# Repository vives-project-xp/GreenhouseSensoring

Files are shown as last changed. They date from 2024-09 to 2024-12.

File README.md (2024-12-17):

# GreenhouseSensoring

## Inhoudsopgave

- [GreenhouseSensoring](#greenhousesensoring)
  - [Inhoudsopgave](#inhoudsopgave)
  - [Doel](#doel)
  - [Gebruik](#gebruik)
  - [Team](#team)
  - [Sensoren](#sensoren)
- [Meer informatie nodig?](#meer-informatie-nodig)
  - [Alle sensoren uitgelegd:](#alle-sensoren-uitgelegd)
  - [Handleiding voor gebruikers:](#handleiding-voor-gebruikers)
  - [Technische documentatie:](#technische-documentatie)
  - [Tips voor mogelijke uitbreidingen en verbeteringen](#tips-voor-mogelijke-uitbreidingen-en-verbeteringen)
- [Bill of Materials (BOM)](#bill-of-materials-bom)

## Doel
Dit project heeft als einddoel het maken van testopstelling voor het meten van verschillende eigenschappen in de serre m.b.v. sensoren en deze waarden uit te lezen met Home Assistant. Aan de hand van 6 sensoren, die in totaal 9 verschillende parameters doorsturen, worden metingen opgenomen via een ESP32 microcontroller. Deze ESP32 stuurt dan via het lokale netwerk de gemeten waardes door naar de lokale Home Assistant server, waar ze op een visuele manier mooi voorgesteld kunnen worden. Op die manier kan informatie opgedaan worden om de planten zo goed mogelijk te verzorgen. Want meten is weten! 

Daarnaast werd ook [technische documentatie](./Documentatie/Technische_documentatie.md) en een [lijst van mogelijke uitbreidingen/verbeteringen](./Documentatie/Mogelijke_uitbreiding.md) opgesteld zodat hierop verder gebouwd kan worden. Ook is er een [handleiding](./Documentatie/Handleiding_gebruiker.md) ter beschikking voor mensen die het product willen gebruiken.

## Gebruik
Het gebruiken van het product is vrij simpel. Wanneer deze in het stopcontact gestopt is, zou de ESP na enkele seconden automatisch verbinding moeten maken. Als deze verbinding kan maken met het Devbit netwerk, zullen de waarden doorgestuurd worden naar home assistant. Indien geen verbinding gemaakt kan worden, zal ook niets verstuurd kunnen worden (ook eventuele seriële data zal niet verstuurd worden). Voor enkele sensoren kan het enkele seconden tot een minuutje duren voor ze hun waardes doorsturen.

## Team
De groep bestaat uit:  
- [Didier Vereecke](https://github.com/MrI2C) • Projectleader
- [Xander Vyvey](https://github.com/vyx04) • Scrum-master
- [Ruben Belligh](https://github.com/RubenBelligh)    
- [Kenrie Vandekerckhove](https://github.com/Kenrie19)  

## Sensoren
Dit zijn de sensoren die we gaan gebruiken:
- **Temperatuur/Vochtigheid Sensor**: Meet zowel de temperatuur als de luchtvochtigheid binnen de serre.
- **Lichtintensiteitssensor**: Meet de hoeveelheid licht die de planten ontvangen.
- **Bodemvochtsensor**: Meet het vochtgehalte van de grond.
- **Bodemtemperatuursensor**: Meet de temperatuur van de grond.
- **CO2-sensor**: Meet het CO2-gehalte in de lucht binnen de serre.
- **NPK Sensor**: Meet de concentraties van stikstof (N), fosfor (P), en kalium (K) in de bodem.

# Meer informatie nodig?
## Alle sensoren uitgelegd:
  - [Algemene informatie sensoren](./Documentatie/Algemene%20info%20componenten/README.md)

## Handleiding voor gebruikers:
  - [Handleiding](./Documentatie/handleiding.md)

## Technische documentatie:
- [Technische documentatie](./Documentatie/Technische_documentatie.md)

## Tips voor mogelijke uitbreidingen en verbeteringen:
  - [Uitbreidingen](./Documentatie/Mogelijke_uitbreiding.md)

# Bill of Materials (BOM)

| **Aantal** | **Korte Omschrijving** | **Totale Kostprijs (excl. BTW)** |
|---|---|---|
| 1 | ESP | € 9,50 |
| 1 | Adapter voor ESP | € 3,22 |
| 1 | Temperatuurs/vochtigheid sensor | € 3,30 |
| 1 | Lichtintensiteitssensor | € 2,23 |
| 1 | CO2 Sensor | € 35,95 |
| 1 | Bodemvochtsensor | € 2,48 |
| 1 | Voedingstofsensor | € 45,35 |
| 3 | Bodemtemperatuur sensor | € 14,83 |
| 1 | TTL to RS485 converter | € 1,57 |
| 3 | Level shifter | € 1,61 |
| 6 | USB-connector met schroefaansluiting | € 4,95 |
| 1 | Verlengkabel USB | € 5,78 |
| 1 | Stekkerkop | € 5,36 |
| 10 | Draden van 0,5mm² (oranje) | € 1,60 |
| 10 | Draden van 0,5mm² (zwart) | € 4,00 |
| 10 | Draden van 0,5mm² (rood) | € 1,40 |
| 10 | Draden van 0,5mm² (wit) | € 1,60 |
| 1 | Adereindhulzen voor 0,5mm² | € 2,31 |
| 6 | Wago's 5P | € 4,93 |
| |Totaal | € 151,97 |

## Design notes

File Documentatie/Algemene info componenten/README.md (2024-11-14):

# Architectuur:
De **ESP32 Devkit V1** board wordt gebruikt als microcontroller voor de aansturing. De ESP zal in een 3D-geprinte behuizing geplaatst worden en verbonden worden aan een speciale adapter om kabels eenvoudiger te kunnen bevestigen.

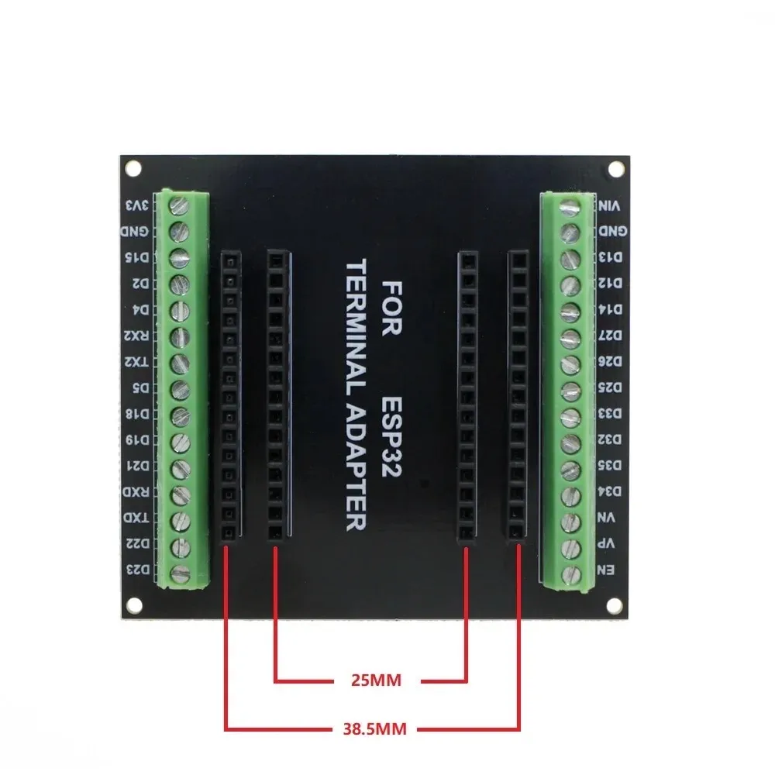
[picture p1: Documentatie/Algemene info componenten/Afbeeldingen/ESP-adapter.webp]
ESP Adapter


# ESP32
De minimale stroomvoorziening voor de ESP32 is 500 mA.

# Sensoren
De volgende 6 sensoren worden gebruikt voor het monitoren van de planten:

## Temperatuur- en vochtsensor omgeving
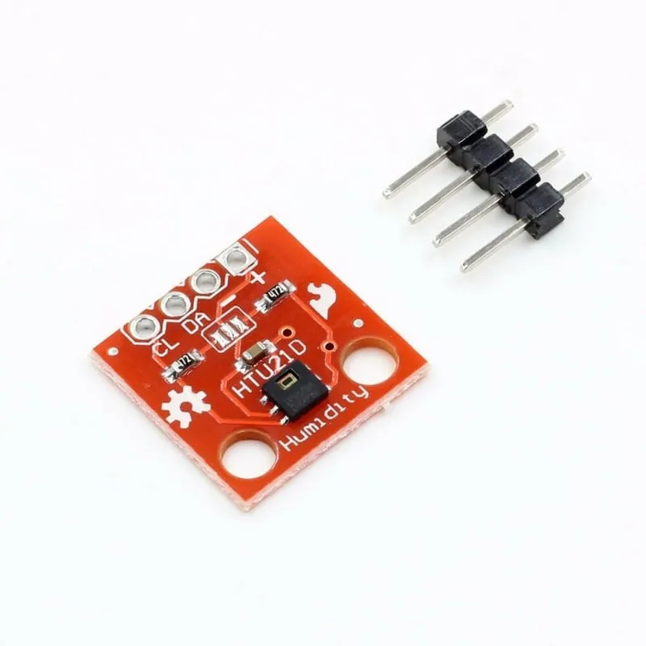
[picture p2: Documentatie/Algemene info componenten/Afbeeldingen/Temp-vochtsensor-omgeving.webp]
Temperatuur- en vochtsensor omgeving


- **Beschrijving:** Deze sensor (Temperatuur/Vochtigheid Sensor Module Breakout - HTU21D (OT3567)) meet zowel de temperatuur als de luchtvochtigheid in de omgeving van de serre. Hiervoor zal een klein doosje geprint worden om deze veilig op te bergen.
- **Elektrische eigenschappen:** Gevoed op 3.3V, direct via de ESP. Stroomverbruik ligt tussen 300 en 500 µA in actieve toestand (tussen 0.02 en 0.14 µA in slaapstand).
- **Overig:** Heeft SCL/SDA-pinnen die rechtstreeks op pin D21 en D22 van de ESP aangesloten kunnen worden. Een andere sensor (lichtsensor) gebruikt ook SCL/SDA, maar beide sensoren hebben een ander I2C-adres, wat geen probleem oplevert. Deze sensor werkt op adres **0x40**.
- **Bronnen:**
  - [Verkooppagina Otronic](https://www.otronic.nl/nl/temperatuur-vochtigheid-sensor-module-breakout-htu.html)

## Lichtintensiteitsensor
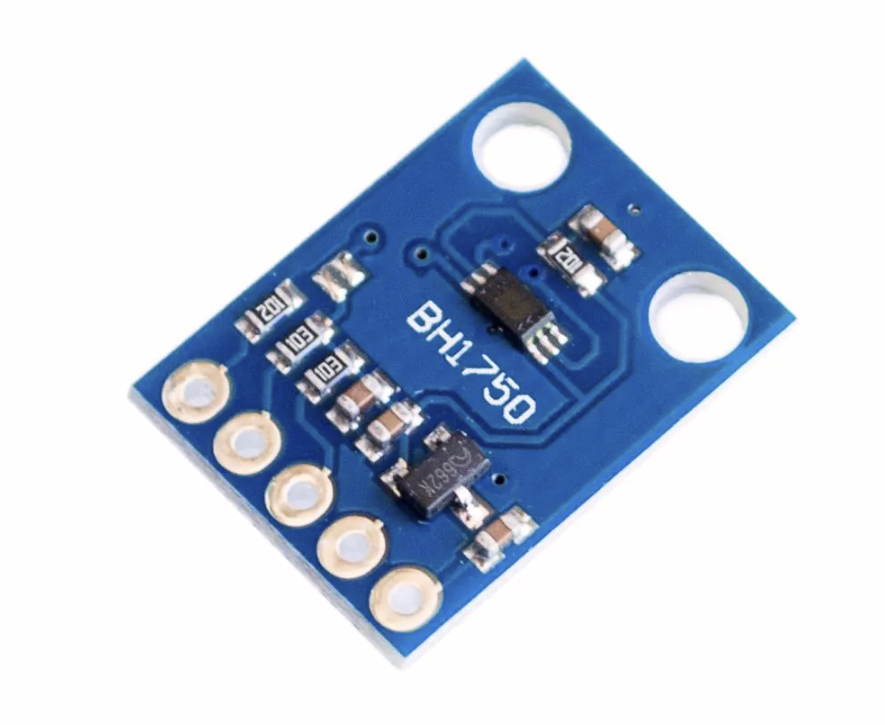
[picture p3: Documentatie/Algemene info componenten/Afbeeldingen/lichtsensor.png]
Lichtintensiteitssensor


- **Beschrijving:** Deze sensor meet de lichtsterkte in de serre en zal op enige afstand van de ESP bevestigd worden in een 3D-geprint doosje. Deze sensor werkt via I2C en heeft twee mogelijke adressen: **0x5C** (als ADDR hoog is) of **0x23** (als ADDR laag is).
- **Elektrische eigenschappen:** Werkt bij een spanning tussen 3V en 5V.
- **Bronnen:**
   - [Verkooppagina Otronic](https://www.otronic.nl/nl/lichtintensiteitssensor-bh1750-16-bit-i2c.html)
  - [Voorbeeldcode met Arduino](https://randomnerdtutorials.com/guide-for-ds18b20-temperature-sensor-with-arduino/)
  - [Instructables Tutorial](https://www.instructables.com/How-to-use-DS18B20-Temperature-Sensor-Arduino-Tuto/)

## Co² sensor
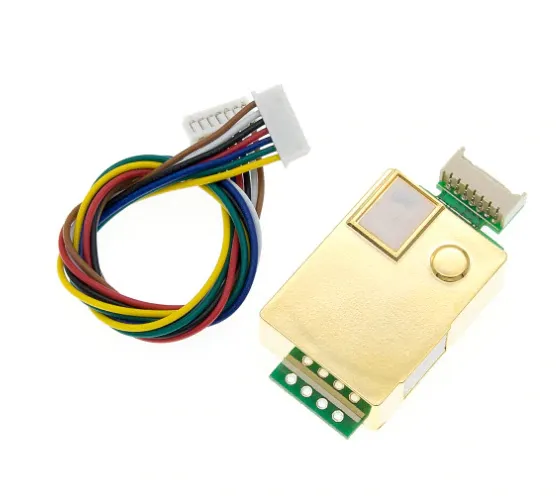
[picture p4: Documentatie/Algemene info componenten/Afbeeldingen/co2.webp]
Co² sensor


- **Beschrijving:** Deze sensor meet de kwaliteit van de lucht (Co² en stikstof). Dit zal in een doosje in een doosje zitten met gaten zodat deze nog goed kan meten. Signalen worden verstuurd door TX en RX uitgang. 
- **Elektrische eigenschappen:** Werkt bij een voeding van 4.5-5.5V DC.
- **Bronnen:**
  - [Verkooppagina Otronic](https://www.otronic.nl/nl/co2-sensor-mh-z19b-met-kabeltje.html)

## Bodemvochtsensor
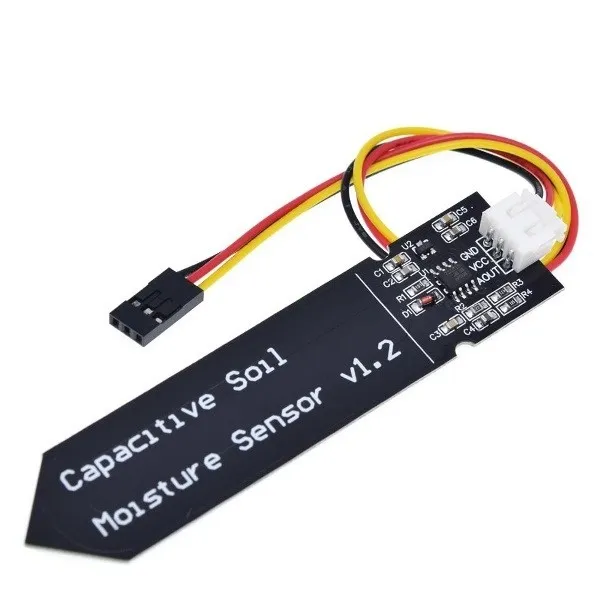
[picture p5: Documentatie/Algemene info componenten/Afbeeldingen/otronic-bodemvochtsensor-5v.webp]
bodemvochtsensos

- **Beschrijving:** Deze sensor zal de vochtigheid meten van onze grond. Deze wordt gevoed met 5V voeding. Met een signaalkabel worden de gegevens naar de esp gezonden.
- **Elektrische eigenschappen:** Deze sensor werkt op 5V.
- **Bronnen:**
  - [Verkooppagina Otronic](https://www.otronic.nl/nl/bodemvochtsensor-met-voltage-regulator-copy.html)

## Bodemtemperatuursensor
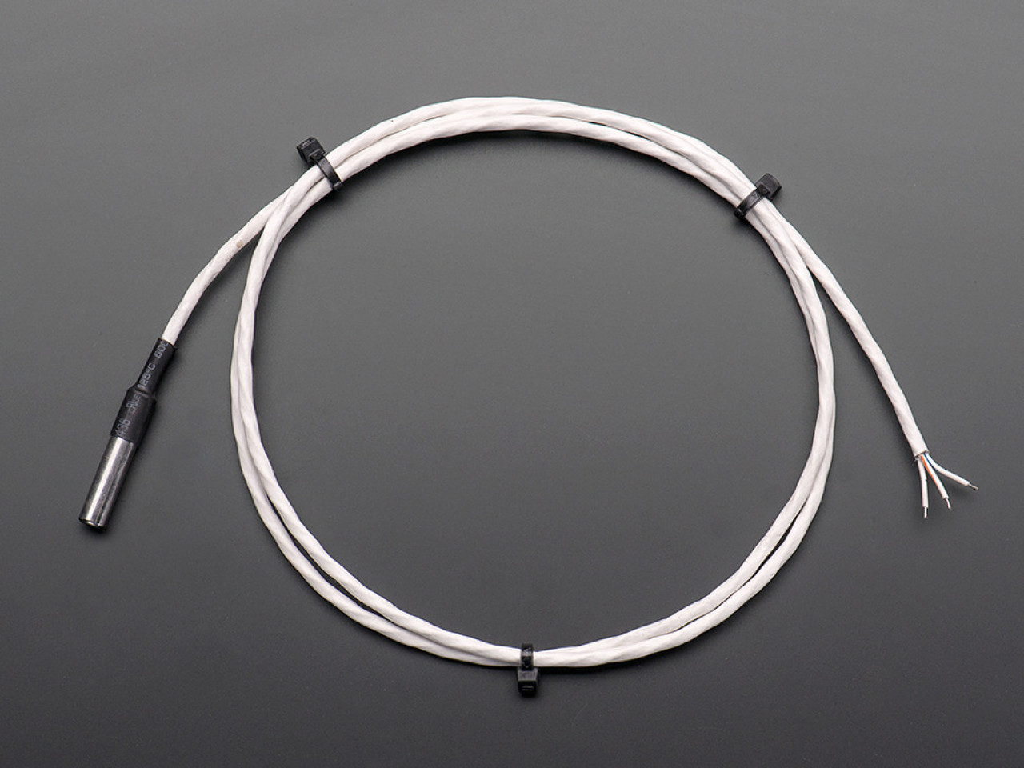
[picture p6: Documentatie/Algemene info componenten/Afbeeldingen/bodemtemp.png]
Bodemtemperatuursensor

- **Beschrijving:** Dit is een Bodemtemparatuursensor en zal in de grond zitten. Waar het de temperatuur zal meten, dit wordt doorgestuurd met een signaal kabel naar de esp.
- **Elektrische eigenschappen:** Werkbaar bij een spanning tussen 3.0V en 5.5V.
- **Overige:** Werkt tussen de -55 en 125 graden.
- **Bronnen:**
  - [Verkooppagina Kiwi Electronics](https://www.kiwi-electronics.com/nl/hoge-temp--waterbestendige-ds18b20-digitale-temperatuursensor-plus-weerstand-1431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)

## Voedingstofsensor
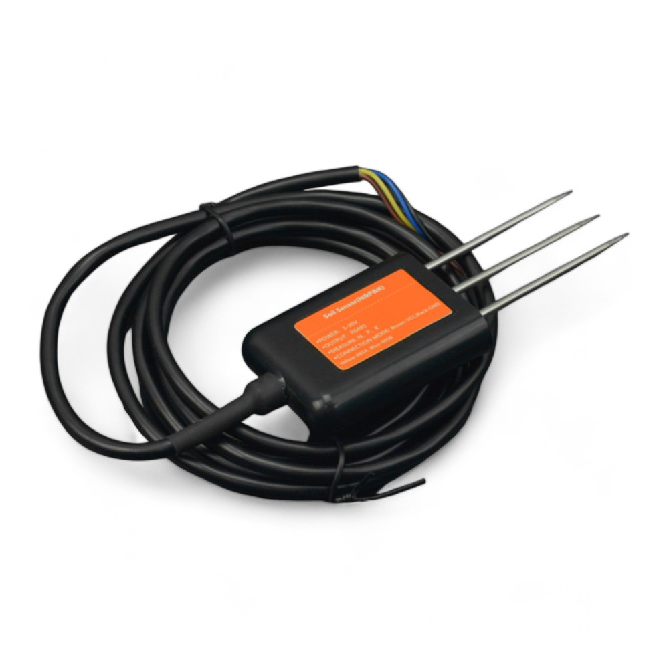
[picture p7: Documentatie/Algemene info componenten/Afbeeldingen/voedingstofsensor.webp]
Voedingstofsensor

- **Beschrijving:** De voedingstofsensor ookwel NPK sensor genoemd meet drie dingen uit. De stikstof, de fosfor en de kalium. Dit kan niet rechtstreeks uitgemeten worden op de esp, hiertussen moet je een TTL -> RS485 plaatsen. Om een goed signaal te kunnen krijgen op de esp.
- **Elektrische eigenschappen:** Deze sensor werkt tussen de  5V en 30V.
- **Overige:** Maximum temperatuur is 80°C.
- **Bronnen:** 
  - [Verkooppagina Mouser](https://www.mouser.be/ProductDetail/DFRobot/SEN0605?qs=sGAEpiMZZMu3sxpa5v1qrmro%252BbykgF%2FHBGnWfOZZDls%3D)
  - [Aansluitschema's](https://how2electronics.com/iot-based-soil-nutrient-monitoring-with-arduino-esp32/#:~:text=So,%20this%20is%20how%20you%20can%20make%20a)

# Schema van de aansluitingen
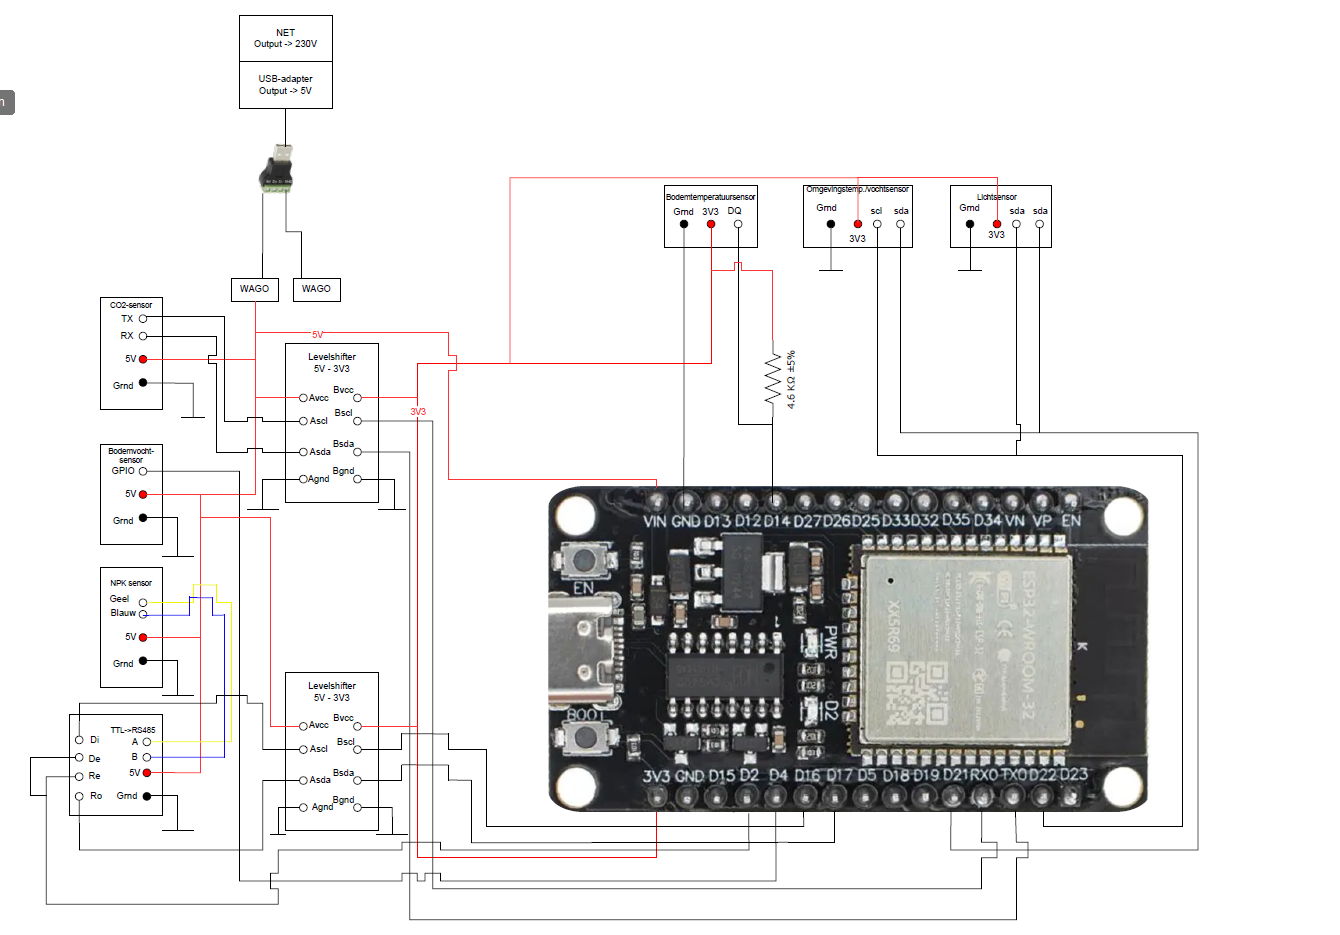
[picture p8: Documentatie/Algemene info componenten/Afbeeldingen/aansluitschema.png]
aansluitschema


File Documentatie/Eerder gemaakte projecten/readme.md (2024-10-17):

1. Info over de vochtigheidsSensor en NPK sensor

https://how2electronics.com/iot-based-soil-nutrient-monitoring-with-arduino-esp32/#:~:text=So,%20this%20is%20how%20you%20can%20make%20a

2. UV sensor aansluiting

https://youtu.be/UsLcHSbxf_8

3. Aansluiting voor de CO2 sensor

https://www.electroniclinic.com/mh-z19b-ndir-co2-sensor-with-arduino-mhz19b/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

4. Bodemvochtsensor / temperatuur

https://microcontrollerslab.com/esp32-htu21d-temperature-humidity-sensor-tutorial/

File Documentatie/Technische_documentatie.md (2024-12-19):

# Technische documentatie

In dit document werd alle benodigde technische documentatie van de testopstelling samengebracht om eventueel te kunnen bouwen hierop. Specifieke schema's of datasheets zijn te vinden onder de mapjes [Hardware](../Hardware/) en [Datasheets](../Datasheets/). Mogelijke uitbreidingen of verbeteringen voor het product zijn in [dit bestand](./Mogelijke_uitbreiding.md) te vinden. Ook is er een [handleiding](./Handleiding_gebruiker.md) voor het gebruik van het product als eindgebruiker. Het wordt aangeraden om al deze documenten eerst door te nemen alvorens dit document te gebruiken.

## Inhoudsopgave

- [Technische documentatie](#Technische-documentatie)
  - [Extra sensoren toevoegen aan project](#Extra-sensoren-toevoegen-aan-project)
  - [Vervangen tijdelijke ESP32](#Vervangen-tijdelijke-ESP32)
  - [Toevoegen omgevingstemperatuursensor](#Toevoegen-omgevingstemperatuursensor)
  - [Overige info ESP32](#Overige-info-ESP32)

## Extra sensoren toevoegen aan project
In dit onderdeel wordt besproken hoe je nieuwe sensoren kan toevoegen aan dit project.

### Stap 1
Denk na over wat je wilt meten en welke sensor je hiervoor kan gebruiken. Deze sensor kan alleen op 5V of 3.3V werken. Indien een sensor op een hogere spanning werkt, zal dit niet compatibel zijn met ons systeem en zal een aparte manier van voeden gebruikt moeten worden voor die component. Ook is het gebruik van een step-down-converter aangeraden om de ESP32 niet te beschadigen.

### Stap 2
Maak met de datasheets een architectuurschema zodat je zeker weet hoe deze sensor aan te sluiten is op de ESP. Later kun je o.a. bij fouten hierop terugkomen, een duidelijk schema is dus van groot belang! Kijk hierbij ook van welk communicatieprotocol de sensor gebruik maakt en welke pinconfiguraties hier voor nodig zijn.

### Stap 3
Schrijf de code voor de ESP zodat deze de sensorwaardes kan weergeven (serieel om te testen en/of via home assistant) In veel gevallen is voorbeeldcode online te vinden als je het specifieke typenummer van de sensor opzoekt. Deze voorbeeldcode kan vaak een goed vertrekpunt zijn. Je kan ook altijd kijken naar de code van de reeds geïmplementeerde sensoren, hieronder de belangrijkste code van de lichtsensor ter illustratie (zie commentaar ernaast):
```
#include <BH1750.h> // voor deze sensor wordt gebruik gemaakt van deze library. Dit is te dowloaden adhv de platformIO extensie in VS code (ga naar boards en selecteer daar eerst het type bord, daarna kan onder libraries een library gezocht en toegekend aan een project worden)

HaSensor lichtWaarde; // initialisatie van naam sensorwaarde voor home assistant

BH1750 lightMeter;

void setup()
{
  lightMeter.begin(); // initialiseren van lightmeter in setup

  if (!lightMeter.begin()) { //optionele error-handling
    Serial.println("BH1750 initialisatie mislukt! Controleer de verbinding.");
  }

  //connectie met home assistant opzetten:
  connection =  HaConnection(WIFI_SSID, WIFI_PASSWORD, "IP-ADRES", 8123);
  connection.setup();
  if (!connection.connected)
    return;

  lichtWaarde = HaSensor("Light", SensorType::LIGHT,0,10000);

}

void loop() { 
  //adhv library data verkrijgen en schrijven:
  float lux = lightMeter.readLightLevel();
  Serial.print("Light: ");
  Serial.print(lux);
  Serial.println(" lx");
  Serial.println("");

  //en versturen naar home assistant:
  lichtWaarde.setValue(lux);
  std::vector<HaSensor> sensors = {lichtWaarde}; // hier kunnen andere sensoren in worden toegevoegd
  connection.sendData("Sensoring", sensors);
  delay(5000);

```

### Stap 4
Als de sensor geleverd is test je deze best eerst even uit in een testopstelling om te kijken of alles werkt. Dit kan bvb. op een breadboard zijn en enkel serieel versturen van data. Dan kan via een applicatie als putty gekeken worden of er waardes gestuurd worden.

### Stap 5
Nu kan je de sensor solderen in de echte opstelling. Doe dit in een veilige omgeving. Als de sensor geplaatst is en werkt dan ben je in principe klaar. Nu kan via home assistant gekeken worden of de waardes correct verstuurd worden (opgelet: op home assistant moeten ook nog enkele dingen opgezet worden, kijk daarvoor in de documentatie van team GH-Networking and monitoring).

## Vervangen tijdelijke ESP32

Om de tijdelijke Devkit V1 te vervangen met de voorziene ESP32 USB-C WROOM, moeten de volgende simpele stappen voldaan worden:

### Stap 1
Eerst en vooral moet de code upgeload worden naar de nieuwe ESP.

### Stap 2
Verwijder de tijdelijke ESP en alle kabels die deze verbinden met het adapterbord. Deze zijn niet meer nodig, waardoor het doosje een stuk overzichterlijker zal worden.

### Stap 3
Hierna moeten de pinaansluitingen voor voor enkele sensoren fysiek veranderd worden. Voor de sensoren die gebruik maken van I2C moet SCL aan pin D22 en SDA aan pin D21 hangen. Aangezien I2C met adressen werkt kunnen beide sensoren aan deze datapinnen hangen. Dit moet dus op het adapterbordje veranderd worden.

### Stap 4
Wanneer de ESP32 nu op de juiste manier op het adapterbordje bevestigd zal worden (kijk hiervoor naar pinnamen op adapter en ESP en kijk of ze overeenkomen), zal alles werken met de nieuwe ESP!

## Toevoegen omgevingstemperatuursensor
Omdat wij door een defect de omgevingstemperatuursensor niet konden gebruiken, zit deze niet inbegrepen in het project op dit moment. Op volgende manier moet deze toegevoegd worden:

### Stap 1
Sluit de sensor aan, raadpleeg hiervoor het [elektrisch schema](../Hardware/Elektrisch_schema_sensoring.pdf) (kijk naar omgevingstemp./vocht rechtsboven in het schema). 

### Stap 2
Verander nu de code zodat de waardes uitgelezen kunnen worden. Hiervoor moet de code die ongeveer staat op lijn 104-105, 166-174 en 188-189 uit comment gezet worden. Upload nu de code naar de ESP en de data zou serieel verstuurd moeten worden. Om deze ook te zien in het dashboard van home assistant moet opnieuw nog het een en ander toegevoegd worden op de home assistant.

## Overige info ESP32
Indien je code wil uploaden naar de tijdelijke (Devkit v1) ESP, moet tijdens het uploaden de boot knop ingedrukt worden, anders verschijnt een error. Let ook bij het uploaden dat andere seriële programma's die de COM-poort gebruiken, zoals Putty, niet meer openstaan.

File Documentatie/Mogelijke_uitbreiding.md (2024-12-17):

# Mogelijke Uitbreidingen
Onze opdracht is het uitwerken van een testopstelling van de sensormogelijkheden voor een serre. Omdat wij uiteraard gaandeweg in ons project aspecten tegenkwamen die beter zouden kunnen of als extraatje toegevoegd kunnen worden, maakten we hieronder een overzicht op van uitbreidingen die mogelijk toegepast kunnen worden bij een definitievere uitwerking van deze testopstelling. 

## Inhoudsopgave
- [Mogelijke Uitbreidingen](#mogelijke-uitbreidingen)
  - [Inhoudsopgave](#inhoudsopgave)
  - [Meer ESP's](#meer-esps)
  - [Nieuwe Sensoren](#nieuwe-sensoren)
  - [Verbeterde Aansluitingen](#verbeterde-aansluitingen)
  - [Geautomatiseerde Rapportage](#geautomatiseerde-rapportage)
  - [Veiligheidsverbeteringen](#veiligheidsverbeteringen)

## Meer ESP's
Omdat wij de functionaliteit willen aantonen van dit concept, en bijkomend ook met een beperkt budget werken, maakten wij gebruik van 1 ESP-microcontroller. We raden bij een uitbreiding van dit project aan om per plantje een aparte esp te gebruiken, zodat je geen problemen opduiken. Er zijn bijvoorbeeld een beperkt aantal UART poorten op de ESP, waarvan 1 al gebruikt wordt om serieel via USB eventueel data te versturen naar een PC bij het testen. Het gebruik van meerdere ESP's zorgt ook voor een overzichtelijkere opstelling en meer variatie in de plaats van de opstelling. Ook wordt door ons aangeraden om een aparte ESP te voorzien voor sensoren die de volledige omgeving meten (omgevingstemperatuur, vocht, CO2, lichtintensiteit).

## Nieuwe Sensoren
- Sapflow sensor
  - Meet de snelheid van het sap op de plant
- pH-sensor
  - Meet de zuurgraad van de bodem
- Chlorofylsensor
  - Meet het chlorofylgehalte in de bladeren.
- UV-sensor
  - Meet hoeveel UV-straling er is (niet hetzelfde al onze sensor die de lichtintensiteit meet uitgedrukt in lux)

## Verbeterde Aansluitingen en ontwerp
Het kan handig zijn om de draadjes met krimpkousen aan te sluiten, nu hebben we dit met plakband gedaan omdat er geen krimpkous of dergelijk materiaal ter beschikking. Ook zou het goed zijn om voor de lichtintensiteitsensor een doosje te printen in doorzichtige print, wat voor ons niet mogelijk was. Wij gebruikten hiervoor een bestaand doorzichtig doosje, maar dit is uiteraard niet specifiek afgestemd op dit product. Daarbij moet dit ook in een speciaal printmateriaal geprint worden dat tegen zonlicht kan.
Tot slot zou het kunnen helpen om het 3D doosje groter maken in breedte en in hoogte en vakjes te maken om de wago's netjes in te plaatsen. Wij maakten ook geen gebruik van een specifiek ontworpen PCB, grotendeels omwille van de kost. Het adapterbordje voor de ESP zorgt voor een behoorlijke nette oplossing. Indien hiervan meerdere producten gemaakt zouden worden, is een PCB uiteraard een optie.

## Veiligheidsverbeteringen
Mede doordat we gebruik maken van een CO2 sensor die voortdurend wat luchttoevoer moet hebben en we de componenten ook wat wilden verluchten, kozen we ervoor om aan de zijkant van ons doosje gleufjes te plaatsen. Echter is het product hierdoor in principe niet 100 procent waterdicht. Een mogelijke oplossing hiervoor kan het plaatsen van een speciale plastic over het doosje (met open onderkant) dat opengeritst kan worden als men het doosje wil openen.

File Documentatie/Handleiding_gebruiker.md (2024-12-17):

# Handleiding voor de gebruiker van de data

## Aansluiten op netwerk
Het gebruiken van het product is vrij simpel. Wanneer deze in het stopcontact gestopt is, zou de ESP na enkele seconden automatisch verbinding moeten maken. Als deze verbinding kan maken met het Devbit netwerk, zullen de waarden doorgestuurd worden naar home assistant. Indien geen verbinding gemaakt kan worden, zal uiteraard niets verstuurd kunnen worden (ook eventuele seriële data zal niet verstuurd worden). Wanneer de verbinding tot stand gekomen is, kan het voor enkele sensoren enkele seconden tot een minuutje duren voor ze hun waardes doorsturen. De esp heeft een IP-adres dat vaststaat voor die esp, zodat home assistant weet welk specifiek toestel dit is.

## Sensoren en hun waardes
Wie surft naar de home assistant of het dashboard raadpleegd, zal onderstaande tabel zien staan met alle waarden: 

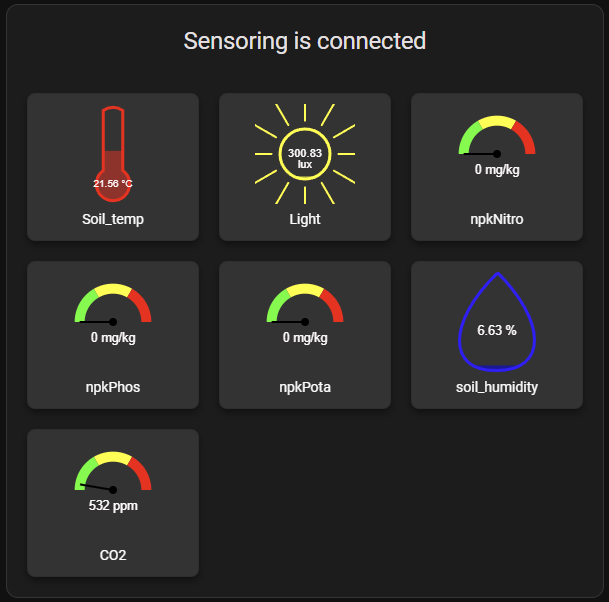
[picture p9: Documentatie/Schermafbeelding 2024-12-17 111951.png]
home-assistant


We zien dat de esp verbonden is met het netwerk en alle sensoren waardes doorsturen. Hieronder overlopen we elke sensor en daarbij ook gemiddelde waardes en wat de waardes willen zeggen voor de plant of omgeving. (Om de meer technische documentatie van sensor te raadplegen, klik [hier](./Algemene%20info%20componenten/README.md).)

### Bodem temperatuur:
De bodemtemperatuur is de sensor met de witte kabel, deze moet voldoende diep in de grond gestopt worden, tot aan de zwarte band ongeveer. Waardes voor de bodemtemperatuur hangen uiteraard af van weersomstandigheden, en meestal kan hier niet veel aan veranderd worden door iemand. Wel geeft het een goede indicatie of de omgeving geschikt is voor de plant. Hoewel dit afhangt van plant tot plant, ligt de gemiddelde waarde voor een goede groei tussen de 8 en 30 graden C.

### Lichtmeter:
Deze sensor meet de lichtintensiteit, uitgedrukt in lux, voor de gehele serre en niet voor 1 plantje specifiek. Uiteraard geldt hoe meer zonlicht, en dus een hogere waarde, hoe beter voor de groei van de plant. Aan de hand van deze gemeten waardes zorgt project Light & Heat voor een verbetering van de lichtintensiteit voor de serre.

### NPK-sensor
De NPK-sensor geeft de voedingstoffen in de bodem weer. Dit zijn Stikstof (N), Fosfor (P) en Kalium (K).
    
    Stikstof is het groeihormoon voor planten en is de allerbelangrijkste stof. Het zorgt voor een goede werking van de fotosynthese, zonder deze stof zal een plant geel worden en zijn bladeren verliezen. Een ideale waarde ligt rond de 20 à 60 mg/kg.

    Fosfor zorgt voornamelijk voor de ontwikkeling van de wortels van een plant, ze worden sterker door fosfor. Een ideale waarde ligt rond de 20 à 50 mg/kg.

    Kalium houdt ten slotte de waterhuishouding in stand. Celwanden van de plant worden erdoor verstevigd, wat zorgt voor een plant met een betere weerstand. Een ideale waarde ligt rond de 100 à 300 mg/kg.

Echter moeten wij bij deze sensor een kleine kanttekening opmaken, deze werkt namelijk niet optimaal. Om goede metingen te hebben, moet de aarde zeer vochtig zijn (bijna modder). In praktijk is dit bijna nooit het geval, waardoor deze zeer vaak de waardes 0 zal doorgeven.

### Bodemvochtsensor
De bodemvochtsensor geeft a.d.h.v. een analoge waarde (die omgezet werd naar een percentage) het vochtigheidspercentage in de bodem weer. Let op dat deze niet te diep in de bodem zit, de witte streep op de sensor is het absolute maximum. Als deze totaal niet vochtig is en gewoon ergens ligt zal een waarde van rond de 4 à 7 procent gegeven worden, dit omdat in de omgeving natuurlijk ook vocht zit. Bij twijfel of de grond te droog is (of net te vochtig), kan deze waarde geraadpleegd worden.

### CO2-sensor
CO2 is een belangrijk onderdeel voor fotosynthese van een plant. Het is belangrijke om een goede balans tussen zuurstof en CO2 te hebben, er moet dus verlucht worden indien nodig. Een ideale CO2 waarde voor de buitenlucht ligt rond de 400 ppm.

### Omgevingsvocht- en temperatuursensor
Momenteel is deze sensor bij ons niet ter beschikking, echter is deze zeer goedkoop en ook zeer simpel aan te brengen, zie [dit document](./Technische_documentatie.md). Deze meet voor de serre in z'n geheel, en niet per plantje. Beide waardes worden door deze sensor gemeten.

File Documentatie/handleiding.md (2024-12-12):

# Handleiding voor Sensoren

## Inhoudsopgave

  [Handleiding voor Sensoren](#handleiding-voor-sensoren)
- [Handleiding voor Sensoren](#handleiding-voor-sensoren)
  - [Inhoudsopgave](#inhoudsopgave)
  - [Inleiding](#inleiding)
    - [Stap 1](#stap-1)
    - [Stap 2](#stap-2)
    - [Stap 3](#stap-3)
    - [Stap 4](#stap-4)
    - [Stap 5](#stap-5)
    - [Stap 6](#stap-6)
  - [Conclusie](#conclusie)

## Inleiding
In deze handleiding wordt besproken hoe je nieuwe sensoren kan toevoegen aan dit project.

### Stap 1
Denk na over wat je wilt meten en welke sensor je hiervoor kan gebruiken. Deze sensor kan alleen op 5V of 3.3V werken.

### Stap 2
Maak met de datasheets een aansluitschema zodat je zeker weet dat het mogelijk is.

### Stap 3
Maak een code voor op de esp met de datasheets van de sensoren/esp. Zorg hierbij dat de waardes correct worden doorgestuurd naar home assistant.
Je kan altijd kijken naar de vorige sensoren hoe dit gebeurd is.

### Stap 4
Als de sensor geleverd is moet je deze eerst testen in een test opstelling. Om te kijken of alles werkt.

### Stap 5
Nu kan je de sensor Solderen in de echte opstelling. Doe dit in een veilige omgeving. Als de sensor geplaatst is en werkt dan bent u klaar. Nu kan je kijken in de home assistent wat de waardes zijn.

### Stap 6
Regelmatig de sensoren controleren op vuiligheid en stof zodat ze optimaal werken.

## Conclusie
Nu kunnen er nieuwe sensoren geplaatst worden in de serre. Als er nog vraagtekens zijn kan je altijd de vorige sensoren bekijken en hun documenten.

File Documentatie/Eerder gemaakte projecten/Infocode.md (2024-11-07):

# Temperatuur en vochtigheidssensor omgeving:
Voorbeeldproject:  https://lastminuteengineers.com/htu21d-temperature-humidity-sensor-arduino-tutorial/ 

1) In PlatformIO de HTU21D library installeren.
2) Volgende code toevoegen aan main.cpp:
```
#include <Wire.h>
#include "Adafruit_HTU21DF.h"

Adafruit_HTU21DF htu = Adafruit_HTU21DF();

void setup() {
  Serial.begin(9600);

  if (!htu.begin()) {
    Serial.println("Couldn't find sensor!");
    while (1);
  }
}

void loop() {
    float temp = htu.readTemperature();
    float rel_hum = htu.readHumidity();
    Serial.print("Temp: "); Serial.print(temp); Serial.print(" C");
    Serial.print("\t\t");
    Serial.print("Humidity: "); Serial.print(rel_hum); Serial.println(" \%");
    delay(500);
}
``` 
# Lichtsensor:
Voorbeeldproject: https://randomnerdtutorials.com/arduino-bh1750-ambient-light-sensor/ 

1) BH1750 (by claws) library installeren 
2) Volgende code toevoegen aan main.cpp:
```
#include <Wire.h>
#include <BH1750.h>

BH1750 lightMeter;

void setup(){
  Serial.begin(9600);

  // Initialize the I2C bus (BH1750 library doesn't do this automatically)
  Wire.begin();
  // On esp8266 you can select SCL and SDA pins using Wire.begin(D4, D3);
  // For Wemos / Lolin D1 Mini Pro and the Ambient Light shield use Wire.begin(D2, D1);

  lightMeter.begin();

  Serial.println(F("BH1750 Test begin"));
}

void loop() {
  float lux = lightMeter.readLightLevel();
  Serial.print("Light: ");
  Serial.print(lux);
  Serial.println(" lx");
  delay(1000);
}
```

# CO2 sensor:
Voorbeeldproject: https://registry.platformio.org/libraries/wifwaf/MH-Z19/examples/RawCO2/RawCO2.ino 

(of https://wolles-elektronikkiste.de/en/mh-z14-and-mh-z19-co2-sensors)

1) MH-Z19 by Jonathan Dempsey library installeren
2) Volgende code toevoegen aan main.cpp:
```
#include "MHZ19.h"
#include <Arduino.h>
#include <SoftwareSerial.h>                                //  Remove if using HardwareSerial or non-uno compatabile device

#define RX_PIN 10                                          
#define TX_PIN 11                                         
#define BAUDRATE 9600                                      // Native to the sensor (do not change)

MHZ19 myMHZ19;                                             
SoftwareSerial mySerial(RX_PIN, TX_PIN);                   // Uno example

unsigned long getDataTimer = 0;

void setup()
{
  Serial.begin(9600);

  mySerial.begin(BAUDRATE);                               // Uno example: Begin Stream with MHZ19 baudrate  
  myMHZ19.begin(mySerial);                                 // *Important, Pass your Stream reference
}

void loop()
{
  if (millis() - getDataTimer >= 2000)
  {

    double adjustedCO2 = myMHZ19.getCO2Raw();

    Serial.println("----------------");
    Serial.print("Raw CO2: ");
    Serial.println(adjustedCO2);

    adjustedCO2 = 6.60435861e+15 * exp(-8.78661228e-04 * adjustedCO2);      
    // Exponential equation for Raw & CO2 relationship

    Serial.print("Adjusted CO2: ");
    Serial.print(adjustedCO2);
    Serial.println(" ppm");

    getDataTimer = millis();

  }
}
```

# Bodemvochtsensor:
Voorbeeldproject: https://www.datocms-assets.com/28969/1662716326-hw-101-hw-moisture-sensor-v1-0.pdf 

# NPK sensor:
Voorbeeldproject: https://community.dfrobot.com/makelog-313566.html?tracking=660bd90501412

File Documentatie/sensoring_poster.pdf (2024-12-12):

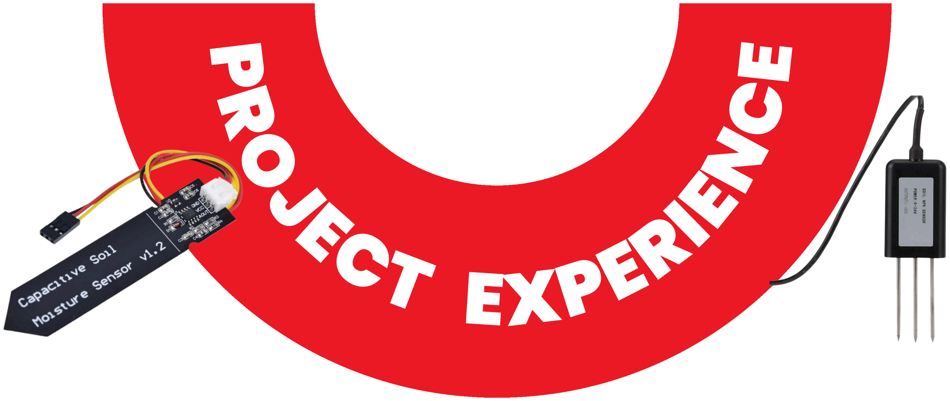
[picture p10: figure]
PROJECT EXPERIENCE

# METEN IS WETEN!

Het doel van ons project is om de groei en gezondheid van planten te monitoren. Dit systeem verzamelt gegevens zoals bodemvochtigheid, temperatuur, lichtintensiteit en andere omgevingsfactoren die van invloed zijn op de plant. Het biedt gebruikers real-time informatie en waarschuwt hen wanneer de plant extra aandacht nodig heeft, bijvoorbeeld bij te weinig water of slechte lichtomstandigheden.

Ons project bestaat uit het ontwerpen en implementeren van een sensor-gebaseerd systeem. We

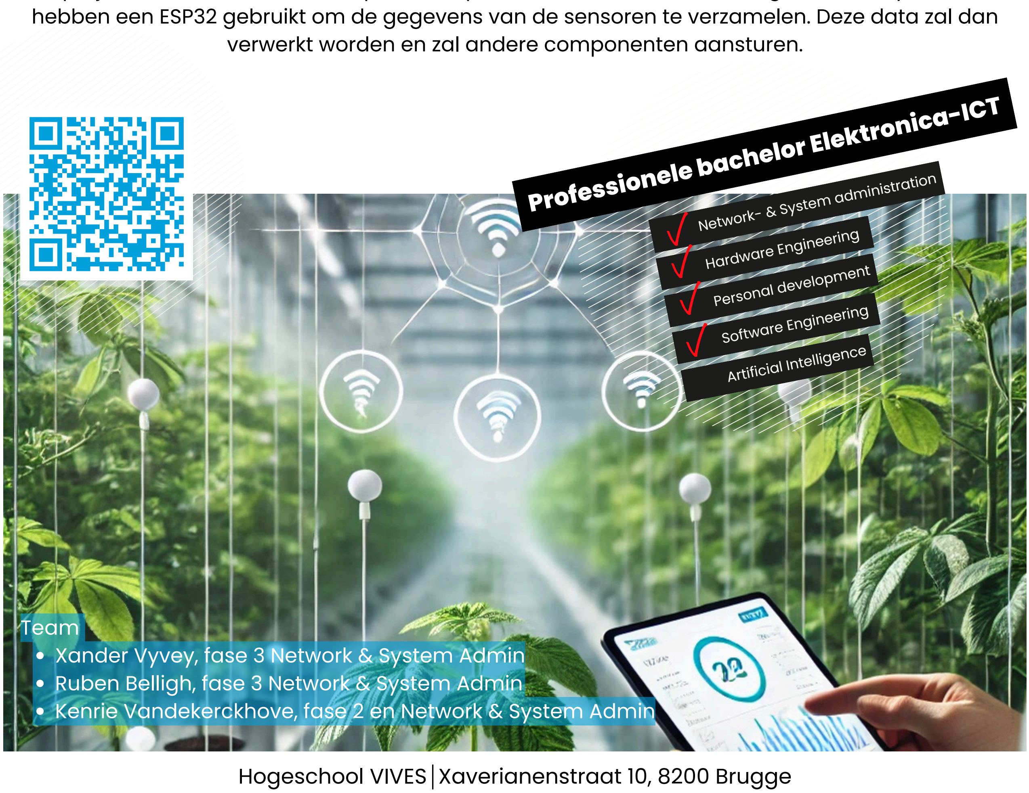
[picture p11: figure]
Professionele bachelor Elektronica-ICT; Software Engineering; Hardware Engineering; Personal development; Network- & System administration; Team; Hogeschool VIVES; Xaverianenstraat 10, 8200 Brugge; Artificial Intelligence

hebben een ESP32 gebruikt om de gegevens van de sensoren te verzamelen. Deze data zal dan verwerkt worden en zal andere componenten aansturen.

# GREENHOUSE SENSORING

Xander Vyvey, fase 3 Network & System Admin
Ruben Belligh, fase 3 Network & System Admin
Kenrie Vandekerckhove, fase 2 en Network & System Admin

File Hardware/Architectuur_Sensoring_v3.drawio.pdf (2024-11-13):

Omgevingstemp./vochtsensor

Step-Down 220V naar 5V

Microcontroller

# Architectuurdocument

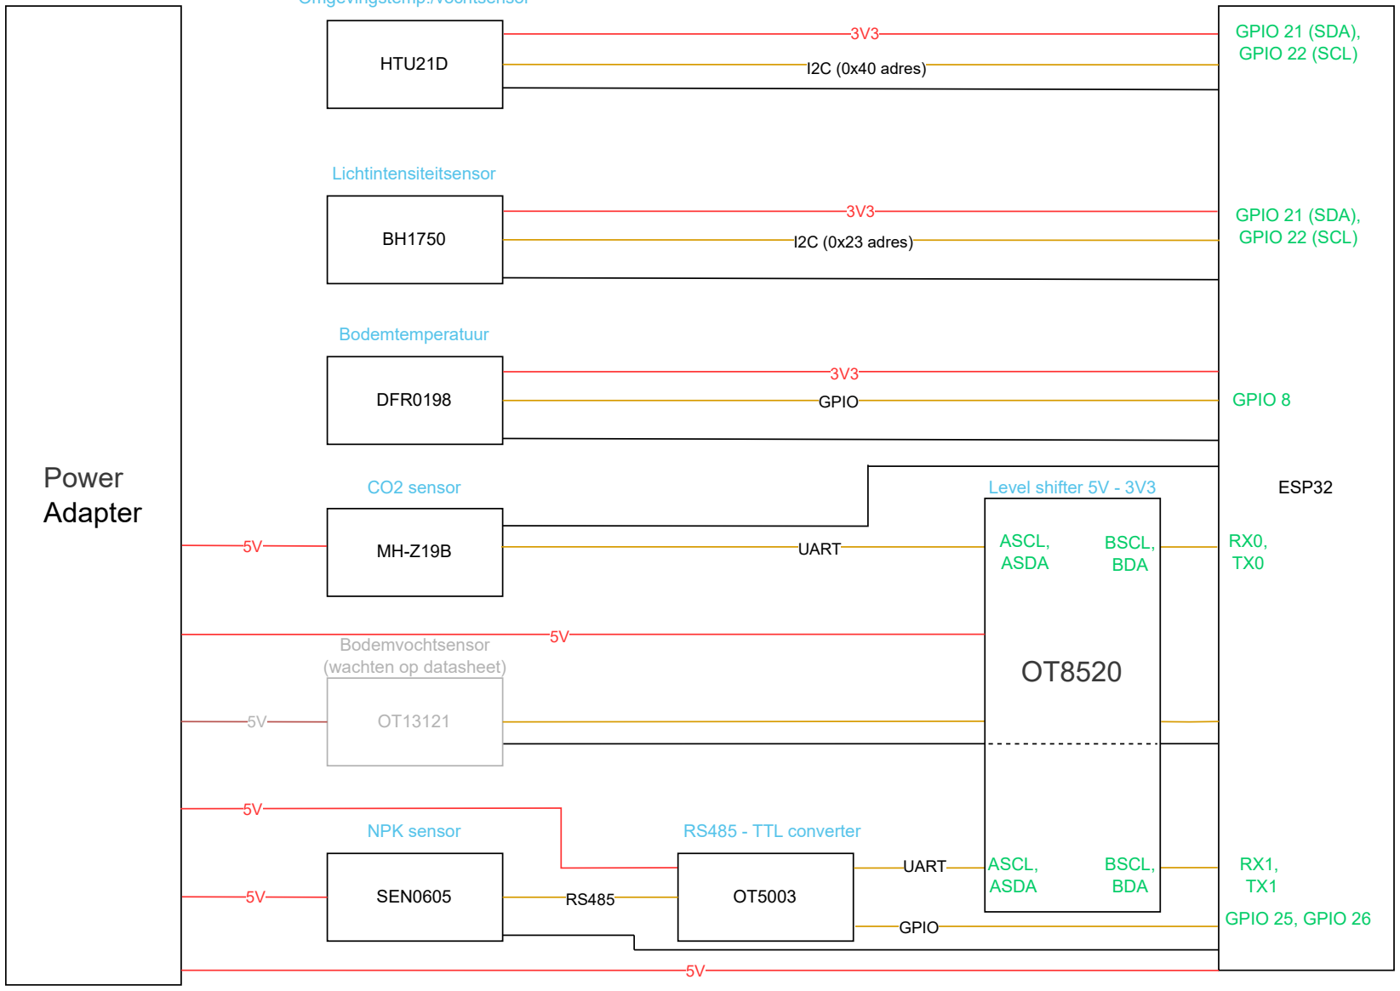
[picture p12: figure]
Powe; ESP32 r; Adapter; HTU21D; Lichtintensiteitsensor; DFR0198; Bodemtemperatuur; CO2 sensor; Bodemvochtsensor (wachten op datasheet); SEN0605; ASDA BDA; NPK sensor; I2C (0x40 adres); I2C (0x23 adres); GPIO; UART; RS485 - TTL converter; GPIO 21 (SDA), GPIO 22 (SCL); GPIO 8; GPIO 25, GPIO 26 GPIO; ASDA BDA OT8520; Level shifter 5V - 3V3; ASCL,; BSCL,; ASCL, BSCL,

# Project 5 -Greenhouse Sensoring

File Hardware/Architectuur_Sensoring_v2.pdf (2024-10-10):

Omgevingstemp./vochtsensor

Step-Down 220V naar 5V

Microcontroller

# Architectuurdocument

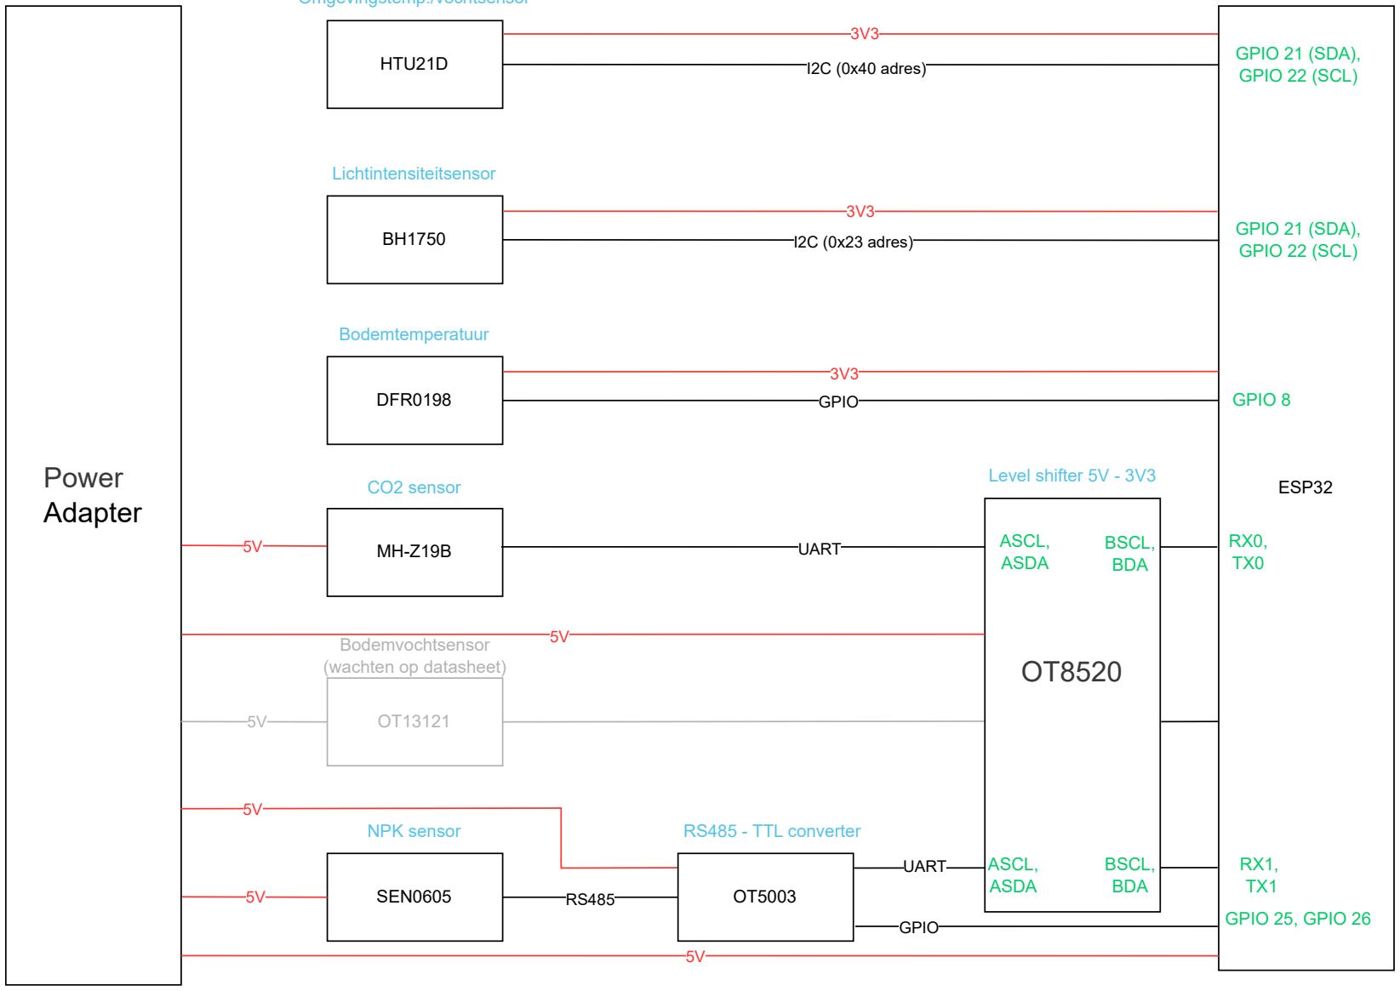
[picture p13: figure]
Powe; ESP32 r; Adapter; HTU21D; Lichtintensiteitsensor; DFR0198; Bodemtemperatuur; CO2 sensor; Bodemvochtsensor (wachten op datasheet); SEN0605; ASDA BDA; NPK sensor; I2C (0x40 adres); I2C (0x23 adres); GPIO; UART; RS485 - TTL converter; GPIO 21 (SDA), GPIO 22 (SCL); GPIO 8; GPIO 25, GPIO 26 GPIO; ASDA BDA OT8520 ASCL, BSCL,; Level shifter 5V - 3V3; ASCL,; BSCL,

# Project 5 -Greenhouse Sensoring

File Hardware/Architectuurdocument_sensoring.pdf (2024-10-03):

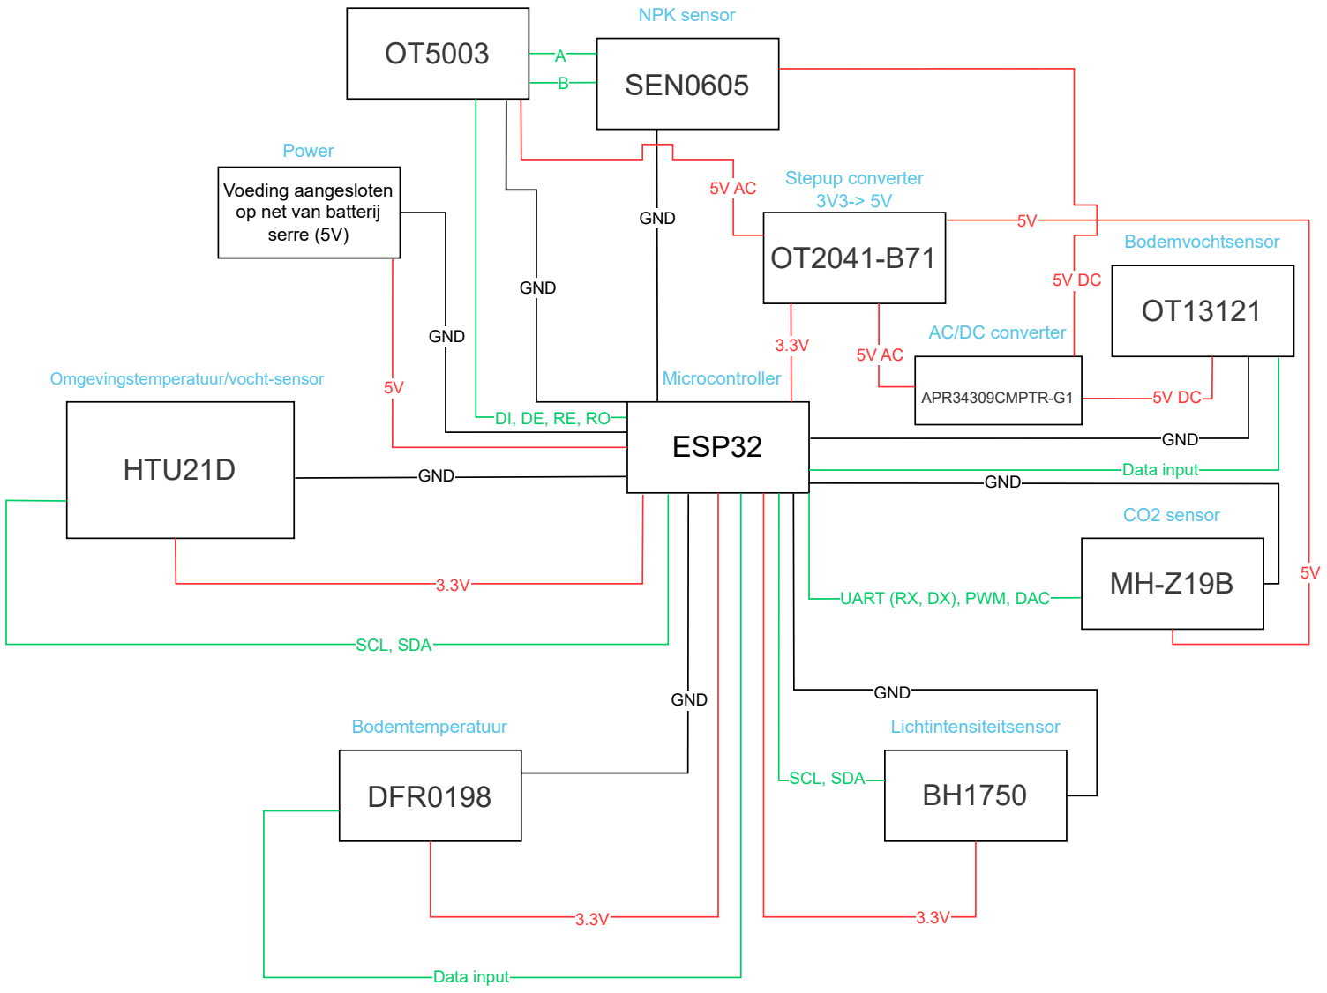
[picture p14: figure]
ESP32; Voeding aangesloten op net van batterij serre (5V); Power; Microcontroller; GND; HTU21D; Omgevingstemperatuur/vocht-sensor; SCL, SDA; DFR0198; Bodemtemperatuur; Data input; Lichtintensiteitsensor; CO2 sensor; UART (RX, DX), PWM, DAC; Bodemvochtsensor; SEN0605; NPK sensor; APR34309CMPTR-G1; AC/DC converter; Stepup converter 3V3-> 5V

TTL to RS485 Converter

# Project 5 - Greenhouse Sensoring

# Architectuurdocument

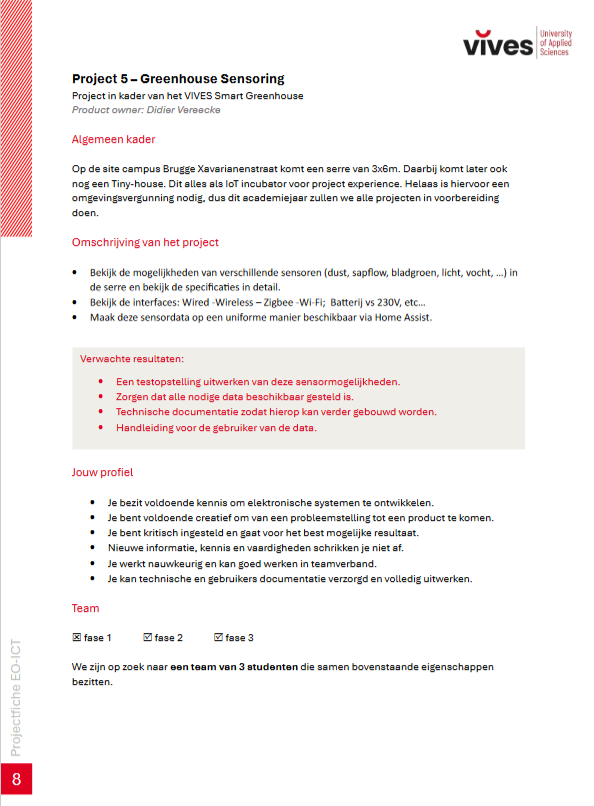
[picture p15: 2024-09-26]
Documentatie/Project_fiche.png

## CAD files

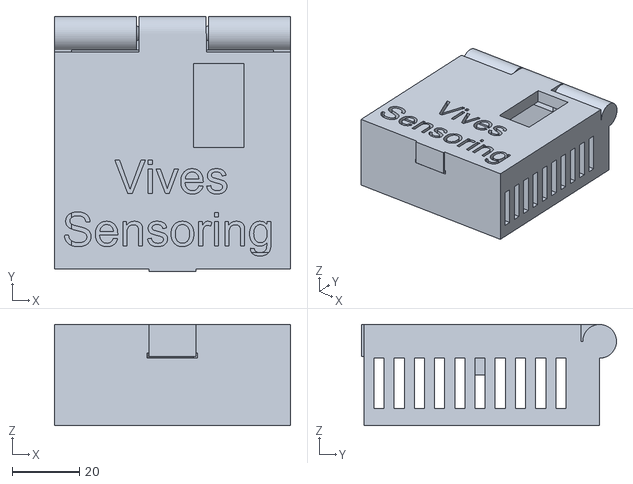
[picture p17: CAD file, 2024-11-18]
3D print files/Versie 1/Doosje voor de sensors v6.stl
70.1 x 75.7 x 30.0

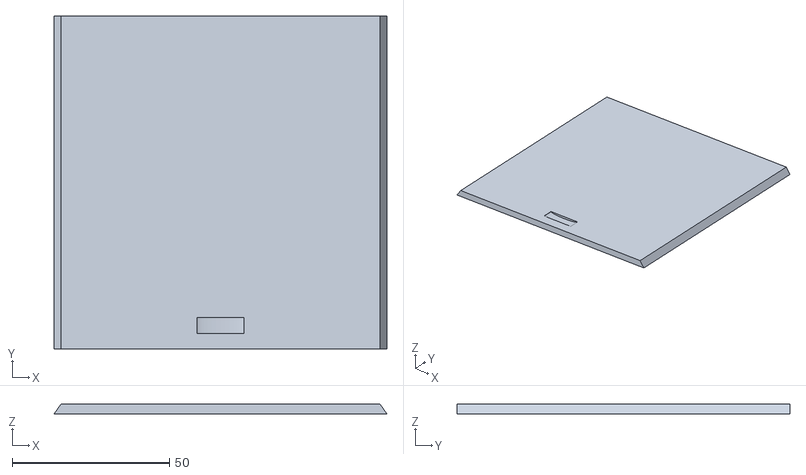
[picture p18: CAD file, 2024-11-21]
3D print files/Versie 2/Deksel voeding 2.0 v1.stl
105.7 x 105.8 x 3.03

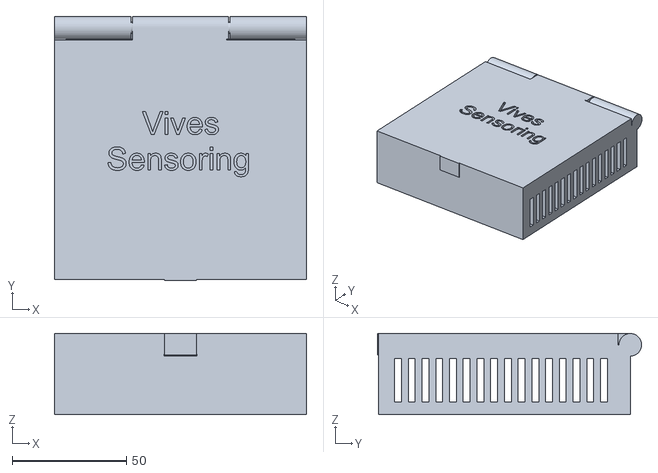
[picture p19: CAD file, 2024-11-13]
3D print files/Versie 1/doosje voeding v6.stl
110.1 x 115.5 x 35.5

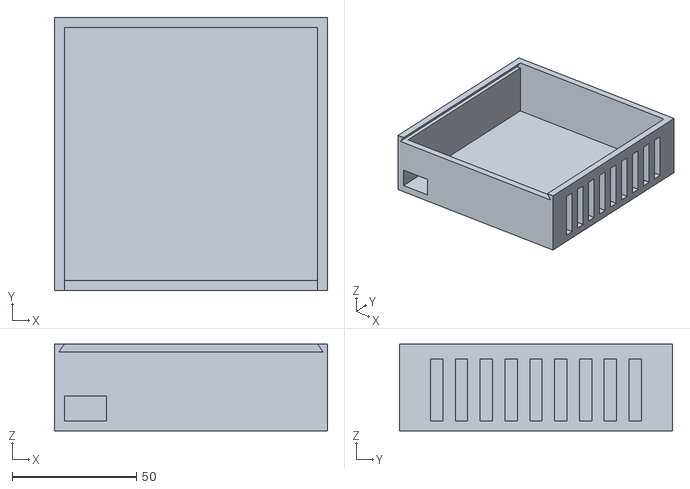
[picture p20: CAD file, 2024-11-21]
3D print files/Versie 2/doosje voeding 2.0.stl
110.0 x 110.0 x 35.0

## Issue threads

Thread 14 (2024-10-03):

Zoeken naar AC/DC converter

vyx04, 2024-10-03:
Het zoeken naar een converter die AC kan omzetten naar DC, de bodemvocht- en NPKsensors werken namelijk op DC (en 5V).

vyx04, 2024-10-10:
Na verder onderzoek blijkt dat deze converter overbodig is bij onze toepassing.

Closed 2024-10-10.

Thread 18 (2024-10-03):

Zelf maken van bruggelijkrichter

vyx04, 2024-10-03:
Het zelf maken van een bruggelijkrichter, aangezien de AC/DC converter een zeer lange levertijd heeft.

vyx04, 2024-10-10:
Dit is niet meer van toepassing in onze architectuur.

Closed 2024-10-10.

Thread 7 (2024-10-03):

Onderzoek naar integratie met home assistant

vyx04, 2024-10-03:
Het onderzoeken naar de manier waarop de data van alle senoren van de esp naar home assistant gestuurd kan worden.

Kenrie19, 2024-10-17:
Alles in JSON file zetten en doorsturen naar de groep Project 8 – Greenhouse Network & monitoring.

Closed 2024-10-17.

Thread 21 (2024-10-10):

Bodemtemperatuur sensor

RubenBelligh, 2024-10-10:
Ik heb een datasheet opgezocht van de bodemtemperatuur sensor. De data en stroom verlopen op dezelfde lijn waardoor er dus een pull-up weerstand nodig is.

Closed 2024-10-10.

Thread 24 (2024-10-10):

Nieuwe step down converter

vyx04, 2024-10-10:
Het veranderen van de step down converter naar een power adapter die netspanning omzet naar 5V. Dit omdat de spanning verkregen van de serre aangepast is van 24V naar netspanning.

Closed 2024-10-10.

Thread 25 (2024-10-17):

Onderzoeken voeding ESP

vyx04, 2024-10-17:
Het opzoeken naar info omtrent het leveren van voeding van de ESP32 aan de componenten, zodat er zeker geen onduidelijkheden bestaan hierrond.

RubenBelligh, 2024-10-17:
In  de datasheet staat vermeld dat de  Minimum current delivered bypower supply 500 mA is. Dit is belangrijk om het circuit goed te laten functioneren.

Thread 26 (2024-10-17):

Onderzoek RS485

vyx04, 2024-10-17:
Het zoeken naar informatie, schema's en dergelijke rondom de RS485 naar TTL converter. Zodat hierover geen onduidelijkheden meer zijn in de implementatiefase.

Kenrie19, 2024-10-17:
De output van de NPK is 8byte binair. (RS485)

Closed 2024-10-17.

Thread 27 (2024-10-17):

ESP32 onderzoek versie

vyx04, 2024-10-17:
Het onderzoeken naar versies van de ESP32, aangezien onze mogelijk een iets oudere versie is. Dit om verwarring te voorkomen tijdens de implementatiefase en eventueel een nieuwere ESP32 voor te kunnen stellen wanneer het prototype van ons sensorproject werkelijk toegepast zal worden.

RubenBelligh, 2024-10-17:
We hebben de ESP32 WROOM V1 en de WROOM 32E vergeleken. De conclusie hiervan is dat de WROOM een nieuwere chipset heeft wat natuurlijk de prestaties zal bevorderen en betrouwbaarder zal zijn. Ook zal er met deze nieuwere chipset langer ondersteuning zijn van de fabrikant. Aangezien ons project een prototype is zal de ESP32 WROOM V1 voldoende zijn.

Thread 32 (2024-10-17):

Testen van de bodemtemperatuur sensor

RubenBelligh, 2024-10-17:
Hierin hebben we de sensor getest met koud water om de functionaliteit uit testen. Daarna hebben we getest of de sensor de juiste temperatuur weergeeft. Dit d.m.v. van lichaamstemperatuur te verifiëren met een thermometer.

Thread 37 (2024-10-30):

Opzoeken Afmetingen

RubenBelligh, 2024-10-30:
We gaan een doosje maken voor de sensoren mooi in op te bergen. Hiervoor heb je de afmetingen nodig van de verschillende componenten.

temperatuur/Vochtigheid sensor: 13,5 x 10,5mm
CO2 sensor:  39 x 20mm
Lichtintensiteit sensor:  13,9 x 18.55mm

Kenrie19, 2024-11-14:
Niet gevonden -> wachten op esp om correcte afmetingen te weten

Closed 2024-11-19.

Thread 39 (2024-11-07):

Research naar voorbeeldprojecten

vyx04, 2024-11-07:
Het zoeken naar voorbeeldprojecten (libraries, code, aansluitingen, veel voorkomende problemen,...) waarin onze sensors gebruikt worden, om zo op een efficiënte manier onze sensoren te kunnen implementeren als ze geleverd zijn.

Closed 2024-11-14.

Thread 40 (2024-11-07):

Gleuven maken in doosjes

RubenBelligh, 2024-11-07:
In de doosjes heb ik gleuven gemaakt zodat de co2 sensor goed kan werken. Aan de bovenkant hebben ik een gat gemaakt zodat het voor de lichtsensor binnenkomt. We kunnen eventueel plexiglas erin plakken op het af te dekken.

Closed 2024-11-19.

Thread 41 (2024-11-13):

Elektrisch schema

RubenBelligh, 2024-11-13:
We hebben het architectuurdocument omgezet in een elektrisch schema. Dit kan er wat ingewikkelder uitzien maar hier staat wel van klem tot klem getekend en dus gedetaileerder, dit kan soms handiger zijn.

Closed 2024-11-14.

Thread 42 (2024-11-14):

Verbeteren code

vyx04, 2024-11-14:
Het verduidelijken en opschonen van de code door o.a. comments en betere benamingen, zodat er geen verwarring zal zijn als de code voor de andere sensoren toegevoegd zal worden.

Closed 2024-11-14.

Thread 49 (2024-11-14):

Programmeren van de sensoren

RubenBelligh, 2024-11-14:
Co2 sensor programmeren. Werkt niet, we krijgen nog geen waarde, we hebben al verschillende libraries uitgeprobeerd zonder resultaat.

vyx04, 2024-11-16:
CO2 sensor werkt, andere pinnen uitgekozen voor UART omdat pinnen voor UART0 gebruikt worden door ESP voor communicatie met PC via USB kabel.

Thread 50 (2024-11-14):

Fixen fout CO2 sensor

vyx04, 2024-11-14:
Opzoeken naar de oorzaak van de CO2 sensor die geen waardes stuurt. Veranderd van UART pinnen naar GPIO 16 en 17.

vyx04, 2024-11-14:
Aangezien de NPK sensor ook werkt via UART en pinnen 1 en 3 niet beschikbaar zijn, kan het volgende waarschijnlijk een oplossing bieden:

De derde UART-interface, UART1, is niet vast toegewezen aan specifieke pinnen en kan geconfigureerd worden met behulp van andere GPIO-pinnen naar keuze.

Extra UART instellen op aangepaste pinnen (UART1)
Je kunt UART1 configureren op elke beschikbare GPIO die kan worden ingesteld als RX en TX. Hier is een voorbeeld voor het instellen van UART1 op bijvoorbeeld GPIO4 en GPIO5:

```

HardwareSerial Serial1(1);  // Gebruik '1' voor UART1

void setup() {
    Serial1.begin(9600, SERIAL_8N1, 4, 5);  // RX op GPIO4, TX op GPIO5
    Serial.begin(9600);  // Standaard seriële communicatie via USB

    // Test de seriële verbinding door iets te sturen
    Serial1.println("UART1 is configured on GPIO4 (RX) and GPIO5 (TX)");
}
```

Closed 2024-11-14.

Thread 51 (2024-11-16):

Aansluiten NPK sensor in testopstelling

vyx04, 2024-11-16:
Het aansluiten van de NPK sensor (verbonden via een levelshifter en TTL-RS485 converter met ESP).

vyx04, 2024-11-16:
Nog geen data verkregen van sensor: mogelijke fouten op hardwarevlak zijn verkeerde UART aansluiting (of configuratie in code ervan), RE & DE op TTL converter niet juist aangesloten,...

Closed 2024-11-16.

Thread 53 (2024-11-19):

Info over Doosje voeding 2.0

RubenBelligh, 2024-11-19:
Aangezien het vorige doosje niet printbaar was door het deksel ben ik op zoek gegaan naar een andere sluit mechanisme. Hier hebben we nu gekozen om een deksel te maken die je erin moet schuiven.

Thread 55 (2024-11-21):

NPK probleem oplossen

vyx04, 2024-11-21:
Momenteel worden van de NPK sensor enkel waarden 0, 2 of 3 verkregen. Wanneer de sensor losgekoppeld wordt, krijgen alle parameters waarde 255 toegekend.

vyx04, 2024-11-28:
Status update: de sensor werkt wel degelijk, maar moet in voldoende vochtige aarde gebruikt worden. Bij droge aarde is er weinig tot geen effect.

Closed 2024-12-05.

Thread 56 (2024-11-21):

bodemvocht stuurt nog niet juiste waardes door

vyx04, 2024-11-21:
De bodemvochtsensor stuurt waardes door (gebeurt analoog), maar die lijken nog niet volledig te kloppen. Wel is er al een sterke verandering in waardes te zien als deze in water gestopt wordt.

vyx04, 2024-11-28:
Analoge waardes omgezet naar een leesbare waarde op een schaal van 0 tot 100 procent. Hiervoor de analoge waarden bij droge en natte omgeving toegevoegd en adhv formule wordt percentage berekend.

Closed 2024-11-28.

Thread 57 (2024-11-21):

Probleem met UART bekijken

vyx04, 2024-11-21:
Wanneer code via een usb kabel moet worden geupload, lukt dit niet als pinnen RE en DE van de RS485 module en pin D12 voor het analoge signaal van de bodemvochtsensor aangesloten zijn op de esp. Proberen om dit op te lossen.

vyx04, 2024-11-28:
Lukt nu wel, analoge pin voor bodemvocht werd verplaatst van D12 naar D35. RE en DE van RS485 bleven op zelfde plaats zitten.

Closed 2024-11-28.

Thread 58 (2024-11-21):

Doorsturen waardes naar Home assistant (+light&heat?)

vyx04, 2024-11-21:
- NPK moet nog doorgestuurd worden (3 verschillende waardes)
- momenteel is type van elke waarde nog TEMPERATURE, moet dus nog aangepast worden.
- light&heat wil mogelijk rechtstreeks data van lichtsensor.

Kenrie19, 2024-12-12:
Nieuwe Esp moet toegevoegd worden

Closed 2024-12-12.

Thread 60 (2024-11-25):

Ontwerpen doosje voor de sensoren 2.0

RubenBelligh, 2024-11-25:
Ik heb een doosje ontworpen voor de sensoren. Maar hier hadden we een probleem. We konden blijkbaar niet printen in doorzichtig PLA waardoor de lichtsensor dus niet optimaal zou werken. Nu hebben we gekozen om een doorzichtig doosje te gebruiken.

vyx04, 2024-12-05:
Opgelost: lichtsensor samen met omgevingstemperatuur- en CO2-sensor in een apart doorzicht doosje geplaatst.

Closed 2024-12-05.

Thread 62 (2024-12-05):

Fout met esp: brownout error

vyx04, 2024-12-05:
Door een foutcode werkt de esp niet in combinatie met de Wifi module.

Kenrie19, 2024-12-12:
Wifi module werkt niet meer.

Nieuwe ESP gebruiken maar niet de juiste want we kunnen gene meer bestellen :( .

Closed 2024-12-12.

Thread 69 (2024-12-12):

Omgevingssensor testen

Kenrie19, 2024-12-12:
Sensor proberen terug aan de praat te krijgen.

vyx04, 2024-12-17:
Fout met sensor, deze dient opnieuw aangekocht te worden. Zie technische documentatie voor het implementeren.

Closed 2024-12-17.

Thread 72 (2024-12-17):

Optimaliseren home assistant integratie

vyx04, 2024-12-17:
Het finaliseren van de manier waarop data gestuurd wordt naar home assistant. Iedere sensor kreeg een eigen type (vb. temperatuur, vocht), ook is er voor elke waarde een min en max meegegeven zodat dit op een visueel mooie manier weergegeven kan worden in home assistant.

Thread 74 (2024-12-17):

Technische documentatie voorzien

vyx04, 2024-12-17:
Het opmaken van technische documentatie waar verder op gebouwd kan worden. Hierin staat o.a. hoe je een sensor kan toevoegen en hoe de tijdelijke esp vervangen kan worden door een nieuwere variant.

Closed 2024-12-19.

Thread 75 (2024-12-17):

Niet functioneren van de CO2 sensor

RubenBelligh, 2024-12-17:
Onze CO2 sensor functioneerde niet naar behoren. Blijkbaar was er een slecht contact met de levelshifter. We hebben dit beter gesoldeerd en het probleem was opgelost.

Closed 2024-12-19.

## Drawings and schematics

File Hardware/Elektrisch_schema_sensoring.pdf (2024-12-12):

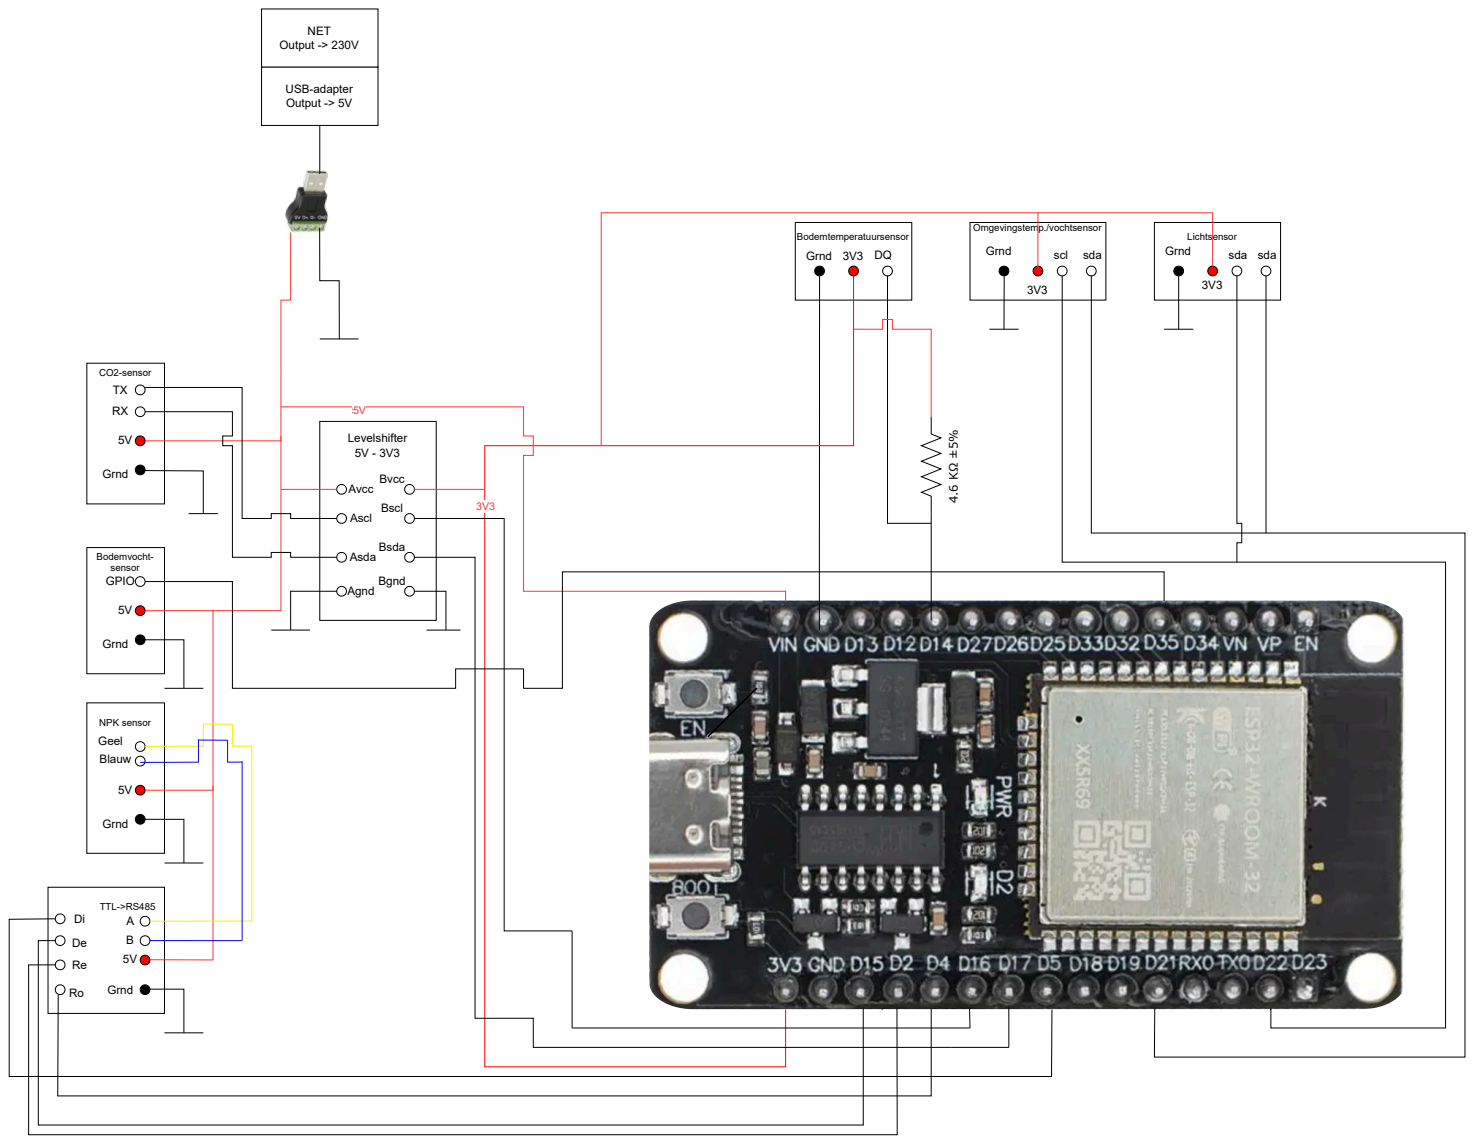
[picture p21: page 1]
NET Output -> 230V; USB-adapter Output -> 5V; Bodemtemperatuursensor; Omgevingstemp./vochtsensor; Lichtsensor; Grnd 3V3; Grnd; CO2-sensor; scl sda; sda sda; Bodemvocht- sensor; NPK sensor; TTL->RS485; GPIO; Ascl; Bvcc Avcc; Bsda; Bgnd; Levelshifter 5V - 3V3; Agnd; Geel Blauw; Bscl; Asda

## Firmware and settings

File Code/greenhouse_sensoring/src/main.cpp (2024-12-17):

//Include libraries
#include <OneWire.h>
#include <DallasTemperature.h>
#include "Adafruit_HTU21DF.h"
#include <BH1750.h>
#include "MHZ19.h"
#include "sensor.h"
#include "connection.h"
#include "info.h"
#include "SoftwareSerial.h"
#include <HardwareSerial.h>

//Initialisatie namen van sensorwaarden voor home assistant
HaSensor bodemTempWaarde;
HaSensor omgevingTempWaarde;
HaSensor omgevingVochtWaarde;
HaSensor lichtWaarde;
HaSensor CO2Waarde;
HaSensor bodemVochtWaarde;
HaSensor NPKWaardeNitro;
HaSensor NPKWaardePhos;
HaSensor NPKWaardePota;
HaConnection connection;

// Datapin bodemtemperatuursensor
#define GPIO_BODEMTEMP 14
OneWire oneWire(GPIO_BODEMTEMP);
DallasTemperature bodemTemp(&oneWire);
float Celsius = 0;

//omgevingtemperatuursensor
Adafruit_HTU21DF htu = Adafruit_HTU21DF();

//lichtsensor
BH1750 lightMeter;

//CO2sensor
#define RX_CO2 16                                       
#define TX_CO2 17
MHZ19 myMHZ19;  
SoftwareSerial mySerial(RX_CO2, TX_CO2);

//npk sensor
#define RX_PIN 4 // Set RX to GPIO4 (voor esp met usbc pin 4)02 16x
#define TX_PIN 5 // Set TX to GPIO5 (voor esp met usbc pin 5)03 17

#define RE 2
#define DE 15

// Modbus RTU requests for reading NPK values
const byte nitro[] = {0x01, 0x03, 0x00, 0x1e, 0x00, 0x01, 0xe4, 0x0c};  // Nitrogen (N)
const byte phos[] = {0x01, 0x03, 0x00, 0x1f, 0x00, 0x01, 0xb5, 0xcc};   // Phosphorus (P)
const byte pota[] = {0x01, 0x03, 0x00, 0x20, 0x00, 0x01, 0x85, 0xc0};

byte values[11];
 
// SoftwareSerial object to communicate with the RS485 module
SoftwareSerial mod(RX_PIN, TX_PIN);

//byte readValue(const byte* request);
byte nitrogen();
byte phosphorous();
byte potassium();

//bodemvocht
int v_droog = 2900;
int v_nat = 1000;

void setup()
{
  // Turn off RS485 receiver and transmitter initially
  digitalWrite(RE, LOW);
  digitalWrite(DE, LOW);
  delay(1000);

  bodemTemp.begin();
  Serial.begin(9600);
  Wire.begin();
  lightMeter.begin();
  mySerial.begin(9600);
  myMHZ19.begin(mySerial);
  
  mod.begin(9600);
 
  // Set RS485 pins as outputs
  pinMode(RE, OUTPUT);
  pinMode(DE, OUTPUT);

  if (!htu.begin()) {
    Serial.println("HTU21DF initialisatie mislukt! Controleer de verbinding.");
}

if (!lightMeter.begin()) {
    Serial.println("BH1750 initialisatie mislukt! Controleer de verbinding.");
}


  connection =  HaConnection(WIFI_SSID, WIFI_PASSWORD, "10.10.2.20", 8123);
  connection.setup();
  if (!connection.connected)
    return;

  bodemTempWaarde = HaSensor("Soil_temp",SensorType::TEMPERATURE,-20,120);
  //omgevingTempWaarde = HaSensor("Ambient_temp", SensorType::TEMPERATURE,-20,120);
  //omgevingVochtWaarde = HaSensor("ambient_Humidity",SensorType::TEMPERATURE,0,100);
  bodemVochtWaarde = HaSensor("soil_humidity",SensorType::HUMIDITY,0,100);
  NPKWaardeNitro = HaSensor("npkNitro", SensorType::NITROGEN,0,1000);
  NPKWaardePhos = HaSensor("npkPhos", SensorType::PHOSPHORUS,0,1000);
  NPKWaardePota = HaSensor("npkPota", SensorType::POTASSIUM,0,1000);
  CO2Waarde = HaSensor("CO2",SensorType::CO2,0,10000);
  lichtWaarde = HaSensor("Light", SensorType::LIGHT,0,10000);

  delay(500); //voor npk 
}

void loop() { 
  byte val1,val2,val3;
  val1 = nitrogen();
  delay(250);
  val2 = phosphorous();
  delay(250);
  val3 = potassium();
  delay(250);

  int CO2 = myMHZ19.getCO2();

  //voor bodemvocht:
  int soilMoistureValue = analogRead(35);  //put Sensor insert into soil
  float vochtigheid = (float(soilMoistureValue) - v_droog) / (v_nat - v_droog) * 100;

  // Zorg dat waarde binnen 0-100% blijft
  if (vochtigheid < 0) vochtigheid = 0;
  if (vochtigheid > 100) vochtigheid = 100;

  // Toon vochtigheid
  Serial.print("Bodemvochtigheid: ");
  Serial.print(vochtigheid);
  Serial.println("%");
  Serial.println("");

  //npk
  Serial.print("Nitrogen: ");
  Serial.print(val1);
  Serial.println(" mg/kg");
 
  Serial.print("Phosphorous: ");
  Serial.print(val2);
  Serial.println(" mg/kg");
 
  Serial.print("Potassium: ");
  Serial.print(val3);
  Serial.println(" mg/kg");
  Serial.println("");

  // De andere sensoren
  bodemTemp.requestTemperatures();  
  Celsius = bodemTemp.getTempCByIndex(0);
  Serial.print("Bodemtemperatuur: ");
  Serial.print(Celsius);
  Serial.print(" C    ");
  Serial.println("");

  float temp = htu.readTemperature();
  float rel_hum = htu.readHumidity();

  // Serial.print("Omgevingstemperatuur: ");
  // Serial.print(temp);
  // Serial.println(" °C");
  // Serial.println("");

  // Serial.print("Omgevingsvochtigheid: ");
  // Serial.print(rel_hum);
  // Serial.println(" %");
  // Serial.println("");

  float lux = lightMeter.readLightLevel();
  Serial.print("Light: ");
  Serial.print(lux);
  Serial.println(" lx");
  Serial.println("");

  //CO2sensor
  Serial.print("CO2 Concentration: ");
  Serial.print(CO2);
  Serial.println(" ppm");

  bodemTempWaarde.setValue(Celsius);
  //omgevingTempWaarde.setValue(temp);
  //omgevingVochtWaarde.setValue(rel_hum);
  lichtWaarde.setValue(lux);
  NPKWaardeNitro.setValue(val1);
  NPKWaardePhos.setValue(val2);
  NPKWaardePota.setValue(val3);
  bodemVochtWaarde.setValue(vochtigheid);
  CO2Waarde.setValue(CO2);
  std::vector<HaSensor> sensors = {bodemTempWaarde, lichtWaarde, NPKWaardeNitro, NPKWaardePhos, NPKWaardePota, bodemVochtWaarde, CO2Waarde};
  connection.sendData("Sensoring", sensors);
delay(5000);

}

// voor npk
byte readSensor(const byte* request, byte* response, int responseLength) {
    digitalWrite(DE, HIGH);
    digitalWrite(RE, HIGH);
    delay(10); // Tijd om te schakelen naar zenden
    mod.write(request, 8); // Stuur Modbus request
    mod.flush(); // Wacht tot het verzenden klaar is
    digitalWrite(DE, LOW);
    digitalWrite(RE, LOW);
    delay(20); // Wacht tot de sensor reageert

    int bytesRead = 0;
    while (mod.available()) {
        response[bytesRead++] = mod.read();
        if (bytesRead >= responseLength) break;
    }

    if (bytesRead < responseLength) {
        Serial.println("Onvolledige respons ontvangen!");
        return 0xFF; // Geef een foutwaarde terug
    }

    // Controleer CRC hier indien nodig (niet geïmplementeerd in dit voorbeeld)
    return response[4]; // Return de waarde (bv. N, P of K)
}

byte nitrogen() {
    byte response[7];
    return readSensor(nitro, response, 7);
}

byte phosphorous() {
    byte response[7];
    return readSensor(phos, response, 7);
}

byte potassium() {
    byte response[7];
    return readSensor(pota, response, 7);
}

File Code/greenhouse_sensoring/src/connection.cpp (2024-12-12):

#include "connection.h"
#include <vector>
#include <ArduinoJson.h>

HaConnection::HaConnection() {};
HaConnection::HaConnection(String ssid, String password): HaConnection(ssid, password, "homeassistant.local", 8123, 80, false) {};
HaConnection::HaConnection(String ssid, String password, String HAIp, int HAPort): HaConnection(ssid, password, HAIp, HAPort, 80, false) {};
HaConnection::HaConnection(String ssid, String password, String HAIp, int HAPort, int port, bool output): ssid(ssid), password(password), server(WiFiServer(port)), HAIp(HAIp), HAPort(HAPort), port(port), output(output){this->setup();};

void HaConnection::StartMDNS()
{
    device_name = "greenhouse" + stringIP();
    if(output) Serial.print("starting MDNS");
    do{
        if (output) Serial.print(".");
        delay(250);
    }
    while (!MDNS.begin(device_name.c_str())) ;
    if (output)
    {
        Serial.print("\nMDNS gestart op ");
        Serial.print(device_name);
        Serial.print(".local\n");
    }
    MDNS.addService("_greenhouse", "_tcp", port);
};

void HaConnection::AttemptWifiConnection()
{
    WiFi.begin(ssid.c_str(), password.c_str());
    if (output) Serial.print("Verbinden met WiFi... ");
    do
    {
        if (output) Serial.println(".");
        delay(250);
    } while (WiFi.status() != WL_CONNECTED);
    Serial.println(WiFi.localIP());
};

void HaConnection::setup()
{
    this->AttemptWifiConnection();
    this->StartMDNS();
    this->connected = true;
    this->checkVersion();
};

void HaConnection::sendData(String card_name, const std::vector<HaSensor>& sensors) {
    String json = "{";

    String name = card_name.length() > 0 ? card_name : "Sensor";
    json += "\"card-name\":\"" + name + "\"," + "\"sensors\":[";
    for (HaSensor sensor : sensors) {
    
        json += sensor.toJson() + ",";
    }
    json = json.substring(0, json.length() - 1);
    json += "]}";
    if(output){
        Serial.println("Sending data: ");
        Serial.println(json);
        Serial.println();
    }

    sendHttpPost(json);
}

void HaConnection::sendHttpPost(String json) {
    if (WiFi.status() == WL_CONNECTED) {
        HTTPClient http;
        String url = "http://" + HAIp + ":" + HAPort + "/api/webhook/greenhouse" + stringIP();
        if(output) Serial.println(url);
        http.begin(url);
        http.addHeader("Content-Type", "application/json");
        int httpResponseCode = http.POST(json);
        if(output){
            if (httpResponseCode > 0) {
                String response = http.getString();
                Serial.println("Response: " + response);
            } else Serial.println("Error in sending POST: " + String(httpResponseCode));
        }
        
        http.end();
    } else {
        if(output) Serial.println("WiFi not connected");
        AttemptWifiConnection();
    }
}



String HaConnection::stringIP() {
    // Verkrijg het lokale IP-adres als een string
    String ip = WiFi.localIP().toString();

    ip.replace('.', '_');

    return "_" + ip;  // Voeg aan het begin een underscore toe
}

void HaConnection::checkVersion() {
    if (WiFi.status() == WL_CONNECTED) {
        HTTPClient http;
        String url = "https://api.github.com/repos/vives-project-xp/GreenhouseNetwork-Monitoring/releases/latest";
        http.begin(url);
        int httpResponseCode = http.GET();
        if (httpResponseCode > 0) {
            String response = http.getString();
            JsonDocument doc;
            deserializeJson(doc, response);
            String latestVersion = doc["tag_name"];
            if (latestVersion != version) {
                Serial.println("New version available: " + latestVersion + " -> https://github.com/vives-project-xp/GreenhouseNetwork-Monitoring/releases");
            }
        }
    }
}

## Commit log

2024-10-03 added datasheet co2 sensor
2024-10-03 added co2 sensor datasheet
2024-10-03 Aanvullen info esp en sensoren
2024-10-10 Aanvullen info sensoren
2024-10-24 added bom list to readme
2024-11-07 Toevoegen van voorbeeldprojecten sensoren
2024-11-14 added co² sensor #30
2024-11-14 Betere foto NPK sensor #43
2024-11-14 Code 4 sensoren werkend + fix CO2 sensor
    [connection.cpp, main.cpp]
2024-11-21 added excel sjabloon #44
    [checklist project.xlsx]
2024-11-21 Checklist version 1 #44
    [checklist project.xlsx]
2024-11-28 Updated checklist #44
    [checklist project.xlsx]
2024-12-12 Powerpoint added
2024-12-12 Code home assistant met alle sensoren
2024-12-12 Checklist ingevuld
    [checklist project.xlsx]
